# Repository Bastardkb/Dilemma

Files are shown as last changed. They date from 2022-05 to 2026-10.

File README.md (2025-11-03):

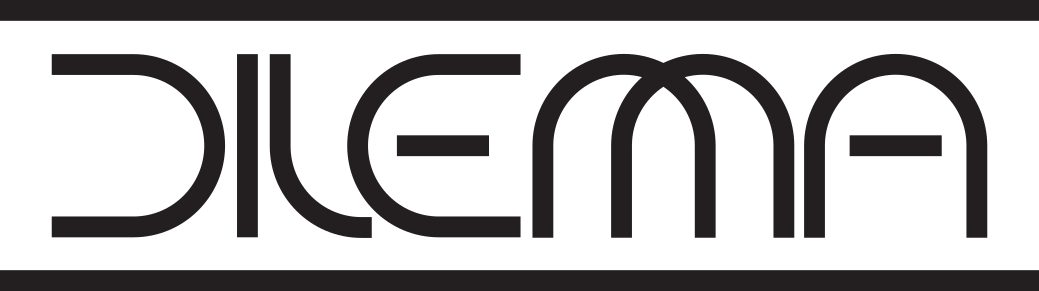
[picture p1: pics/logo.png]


---

The Dilemma is a vertical stagger low-profile keyboard with mods.

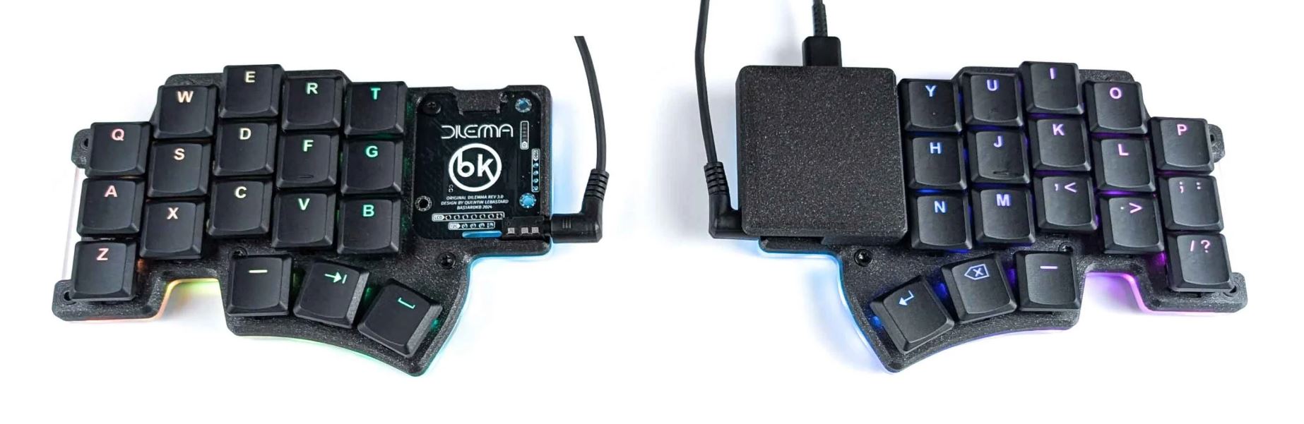
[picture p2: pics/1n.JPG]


## Table of contents

- [Features](#features)
- [Versions](#versions)
- [Required components](#required-components)
  - [3d prints - cases](#3d-prints---cases)
  - [Electronics](#electronics)
  - [Procyon mod](#procyon-mod)
  - [Cirque Trackpad mod](#cirque-trackpad-mod)
  - [Cases](#cases)
    - [Acrylic midplate (v2 only)](#acrylic-midplate-v2-only)
  - [Metal plates](#metal-plates)
  - [Community mods](#community-mods)
  - [Build guide](#build-guide)
  - [Forks](#forks)

---

# Features

- heavy pinky stagger
- MX and choc compatible
- version with hotswap
- underglow RGB, per-key RGB
- 2 Rotary encoders on thumb clusters
- connectors for OLED, LCD

# Versions

There are multiple versions of the dilemma:

| Folder | Name | Size  | PCBA | Trackpad | Switches | Additional features |
| --- | --- | ----- | ---- | --- | --- | --- |
| `3x5_2` | Dilemma DIY V2 | 3x5+2 | no | Cirque | MX, Choc V1 | |
| `3x5_3` | Dilemma V2 | 3x5+3 | yes  | Cirque | MX, Choc V1 | Underglow, per-key RGB, rotary encoders |
| `3x5_3_procyon` | Dilemma V3 hotswap | 3x5+3 | yes  | Procyon  | Choc V1, hotswap | Underglow, per-key RGB, rotary encoders, VIK |
| `4x6_4` | Dilemma MAX | 4x6+4 | yes  | Cirque | MX, Choc V1 | Underglow, per-key RGB, rotary encoders |
| `4x6_4_procyon` | Dilemma MAX V3 hotswap | 4x6+4 | yes  | Procyon  | Choc V1, hotswap | Underglow, per-key RGB, rotary encodersk VIK |

# Required components

## 3d prints - cases

You can find the required 3d prints in the `mechanical` folder.

Most cases require a transparent mid layer to look good. You can either print it, or order it cut in acrylic.

## Electronics

The new revisions are made to be PCBA'd, you can find the gerber, BOM and POS files in the [Releases](https://github.com/bastardkb/dilemma/releases) section.

## Procyon mod

The `dilemma v3 hotswap` is made to work with a [Procyon PCB](https://github.com/bstiq/procyon).

## Cirque Trackpad mod

This mod uses I2C on the DIY version, and SPI on the assembled version.

The DIY version requires removing some resistors from the trackpad:

- R1
- R7 and R8 if you are using a microcontroller that runs on 5V

When installing the trackpad mod, you will need:

| Part name | Amount | Link / source |
| --- | --- | --- |
| M3 screw, torx, 6mm | 4 | Conrad |
| M3x5x5 screw insert | 4 | Aliexpress |
| 3d printed parts | | See `mechanical` folder |
| 40mm cirque trackpad, curved | | |

If building the PCBA version, you will also need:

| Part name | Amount | Link / source |
| --- | --- | --- |
| 12-position FPC cable, 0.5mm pitch, same side contacts, 100mm, type-B | 1 | Farnell |

If building the DIY version, you will also need:

| Part name | Amount | Link / source |
| --- | --- | --- |
| SOD123 Resistor, 5kOhms | 2 | |
| Cables | | |

## Cases

### Acrylic midplate (v2 only)

This case is only compatible with the assembled_v2 version !

Add an underglow effect and a beautiful view into the PCB with those acrylic midplates.

## Metal plates

Optional metal plates enables the use of tripods through magsafe magnets.

Order the [metal plates](mechanical/plates/v2/bottom_metal.dxf) in 3mm thickness. The metal needs to be *magnetized* !
Grab the appropriate DXF from the matched folder.

You will need:

| Part name | Amount | Details |
| --- | --- | --- |
| Metal plates | 2 | 3mm |
| Tripods | 2 | Neewer Z flex |
| Magsafe tripod adapter | 2 | Amazon/Aliexpress |

## Community mods

There are a range of community mods available (hex plates, covers...).

You can find more information in the readme in the `mechanical/community mods` folder.

## Build guide

https://docs.bastardkb.com/bg_dilemma/intro.html

## Forks

- [3x6 version](https://github.com/bstiq/Dilemma_3x6/)
- [3x5 + 3 version](https://github.com/dixls/Dilemma-3mod)

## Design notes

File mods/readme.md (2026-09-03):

# Table of contents
- [Table of contents](#table-of-contents)
- [Cirque holder for flat overlay](#cirque-holder-for-flat-overlay)
  - [BOM](#bom)
  - [Notes](#notes)
- [Blank cover](#blank-cover)
  - [BOM](#bom-1)
  - [Notes](#notes-1)
- [Dilemma Max Tents](#dilemma-max-tents)
- [Dilemma V2  Mounts](#dilemma-v2--mounts)
  - [Table-top tent](#table-top-tent)
    - [Required materials](#required-materials)
  - [Magic arm base](#magic-arm-base)
    - [Required Materials](#required-materials-1)
  - [Design file](#design-file)
- [Trackball mod](#trackball-mod)

# Cirque holder for flat overlay

*This is a community mod, made by Frapiscide*.

A simple holder for the flat overlay cirque trackpad.

Files are in the `40mm_flat_overlay` folder.



## BOM

| Part name | Amount | Notes |
| --- | --- | --- |
| M3x4 Heat-set inserts | 4 |  |
| M3x6 BHCS / SHCS | 4 | |
| 40mm cirque trackpad, flat overlay | 1 | TM040040-2024-302 |
| Pieces of 1.75mm Filament | 3 | 50-75mm is more than enough* |

* If you do not have filament available, alignment key STL's are included

## Notes

- The STL's are pre-oriented for their preferred printing position for FDM
- None of the parts need supports
- The Cirque trackpad holder should work with MX keycaps (18mm x 18mm) but has not been verified. (Rev 1)
- The cirque holder was tested with Cirque Part Number TM040040-2024-302. Others may fit but have not been verified.
- The upper and lower cirque holders require bits of filament and adhesive to hold the two parts together. It was designed this way to prevent the use of supports and maintain dimensional accuracy
- The filament / alignment keys are intentionally a tight fit to maintain alignment.

# Blank cover

*This is a community mod, made by Frapiscide*.

## BOM

| Part name | Amount | Notes |
| --- | --- | --- |
| M3x4 Heat-set inserts | 4 |  |
| M3x6 BHCS / SHCS | 4 | |
| 40mm cirque trackpad, flat overlay | 1 | TM040040-2024-302 |
| Pieces of 1.75mm Filament | 3 | 50-75mm is more than enough* |

## Notes
- The STL's are pre-oriented for their preferred printing position for FDM.
- None of the parts need supports.

# Dilemma Max Tents

*This is a community mod.*

No extras required - same screws and silicon bumpers can be reused.

5,7 and 15 degrees tents are available. Print on flat side. Tolerances might be quite tight, for ABS adjust for shrinkage.

# Dilemma V2  Mounts

*This is a community mod, made by [@brennanxyz](https://github.com/brennanxyz)*.



Files are in the `3x5_3_mounts` folder.

There are two pairs of files for two different tenting solutions, derived from the same base design. One is a table-top set of tent frames, the other is a board bracket meant to be paired with magic arm + clamp tool.

## Table-top tent
These are free-standing, 30° tilting tents that lie on any flat surface. It is designed around the fully-assembled Dilemma V2 stock assembly. 

### Required materials
- (Optional, highly recommended) 8 stick-on rubber feet per half - 7 placed at the tip of each "arm" and once placed at the central nexus point.

## Magic arm base
These are bases that attach to each board half with click-around tabs and are to be paired with a magic-arm mount (such as the SMALLRIG Super Camera Clamp Mount). They are also designed to work with the fully-assembled Dilemma V2 stock assembly.

### Required Materials
- A magic arm + clamp per half. The hole in the base is designed for a 1/4"-20 thread.

## Design file
The design is hosted as an open, free CAD design [on Onshape](https://cad.onshape.com/documents/3a8f56a3f9f7449a7270e859/w/5f722bb2d6442b2bc4cd6168/e/a73e9146248eb1cc832f1ecd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). 
The design by default is for the magic-arm variant, but can be rolled back using the `Rollback bar` to the plane named `DESIGN VARIANT 2` to set the part to the table-top design.

For the magic-arm base, to adjust to a different threaded mount size, edit the sketch named `hole`.

# Trackball mod

*This is a community mod made by Hakuho on Discord*, made for the Dilemma V3.

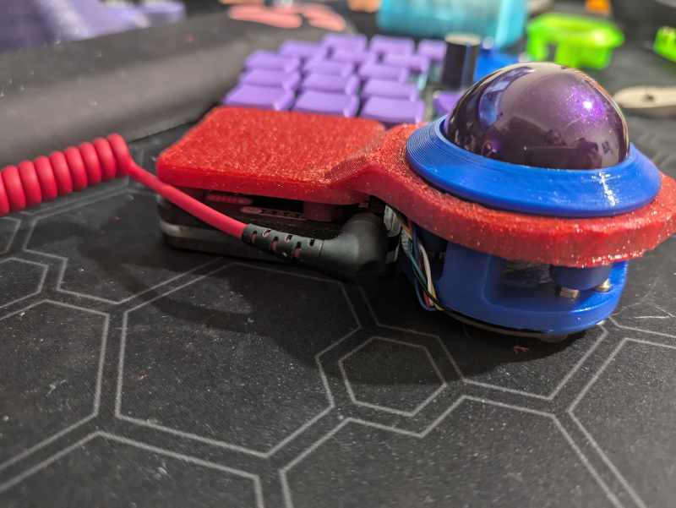
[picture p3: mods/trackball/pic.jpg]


File is in the `mods/trackball` folder.

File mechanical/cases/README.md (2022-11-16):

# 3d printed cases

## Table of contents

- [3d printed thin case](#3d-printed-thin-case)
- [3d printed case with tenting pucks](#3d-printed-case-with-tenting-pucks)
- [3d printed Tenting puck Hex case](#3d-printed-tenting-puck-hex-case)

## 3d printed thin case

Designed for the minimum footprint possible, while still protecting the PCB.

### BOM

| Part name | Amount | Link / source |
| --- | --- | --- |
| M3 screw, torx, 6mm | 6 | Conrad |
| M3 nut | 3 | Conrad |
| Anti slip pads, 10x2mm | 12 | Aliexpress |
| 3d case | 1 right, 1 left | See `mechanical` folder |

### Notes

The case is reversible.

It needs to be printed at 0.2mm layer height supportless specifically for the nut inserts suport-less interfaces. If you are doing a different layer height, use supports. 

## 3d printed case with tenting pucks

Accomodates the Splitkb tenting puck, to be used with a Manfrotto tripod.

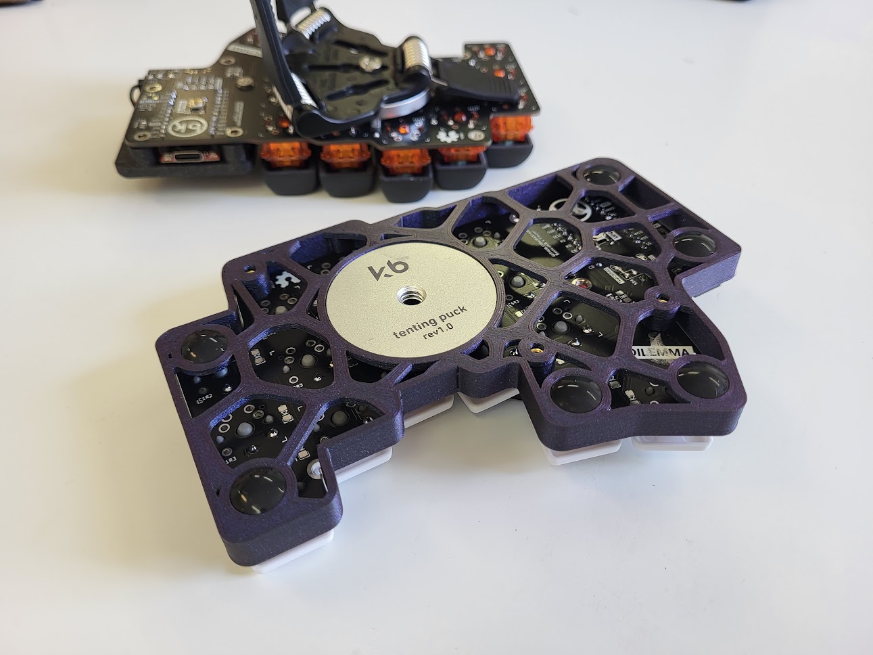
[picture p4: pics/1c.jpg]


### BOM

| Part name | Amount | Link / source |
| --- | --- | --- |
| M3 screw, torx, 6mm | 6 | Conrad |
| M3 nut | 3 | Conrad |
| Anti slip pads, 10x2mm | 12 | Aliexpress |
| Tenting puck assembly  | 1 | Splitkb |
| Manfrotto tripod | 2 | Manfrotto |
| 3d case | 1 right, 1 left | See `mechanical` folder |

### Notes

The case is reversible.

It needs to be printed at 0.2mm layer height supportless specifically for the nut inserts suport-less interfaces. If you are doing a different layer height, use supports.

## 3d printed Tenting puck Hex case

Credit: Frapiscide.

Old-school hex-style cases for the Manfrotto tripod.

There are 2 versions available:

- with a hole for the SplitKB tenting puck
- with an integrated 3d printed puck assembly, to screw the tripod in directly. 

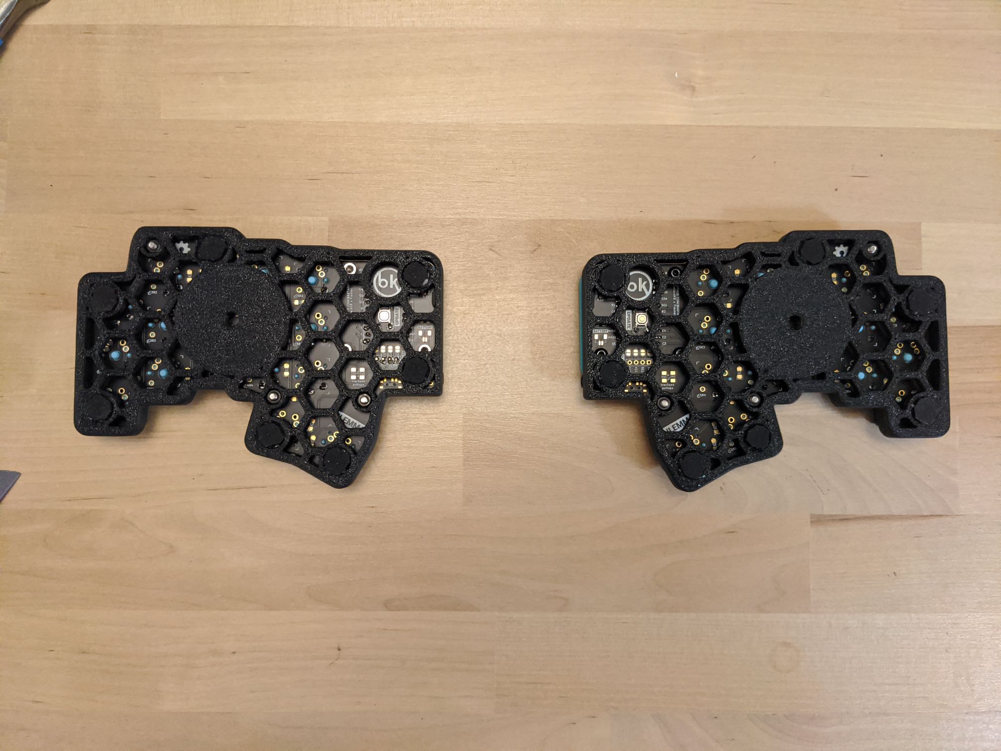
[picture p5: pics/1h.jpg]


### BOM

| Part name | Amount | Notes |
| --- | --- | --- |
| M3x6 BHCS | 3 | M3x8 BHCS work too |
| M3 Hex Nut | 3 | |
| 3d printed case | 2 | Right / Left* |

* You will need to print 2 cases - you can reverse it in your slicing software.

There are 2 versions:
- integrated holes to screw the manfrotto tripod directly
- hole for the splitkb tenting puck 

### Notes

- The case was designed around the DIY v0.1c PCB. Other versions may work but have not been verified
- The STL's are pre-oriented for their preferred printing position for FDM
- None of the parts need supports
- The case has .25mm of clearance all around the perimeter of the PCB
- The parts can be mirrored for whichever side you want the part for. The case and blank cover are originally modelled for the left side and the cirque holder for the right side. (Rev 1)

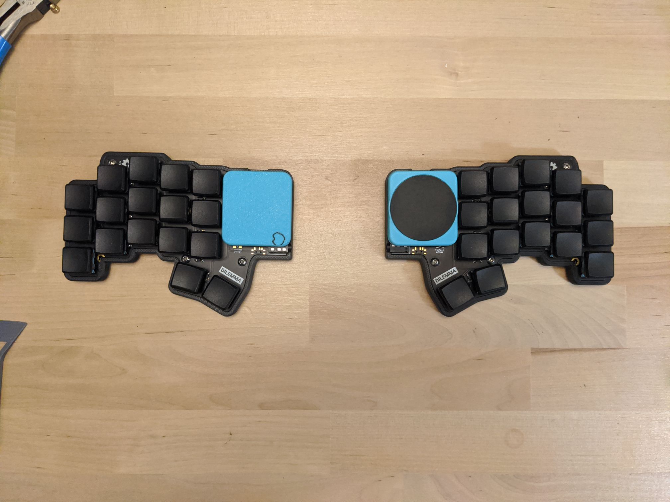
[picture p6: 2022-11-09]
pics/1i.jpg

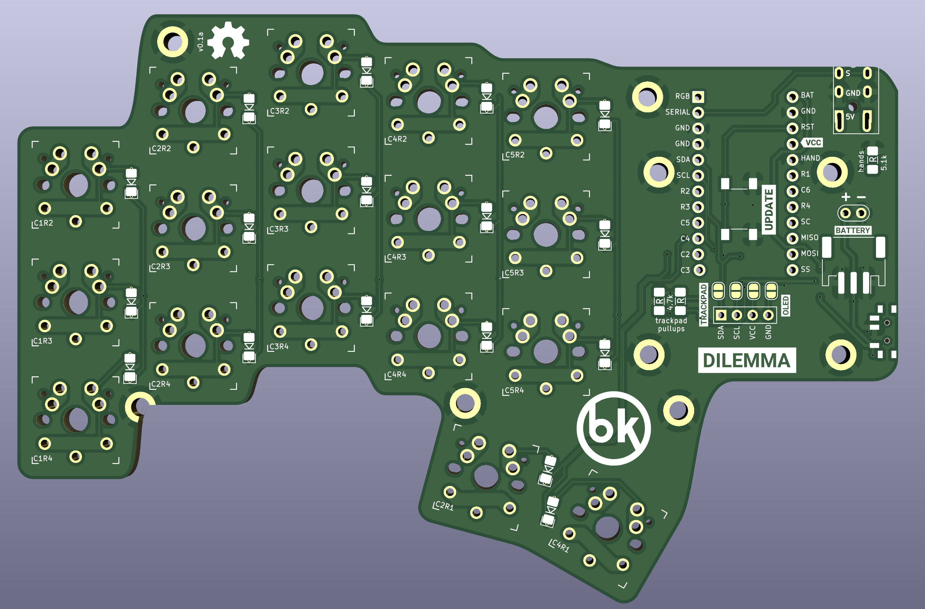
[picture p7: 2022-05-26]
pics/1a.PNG

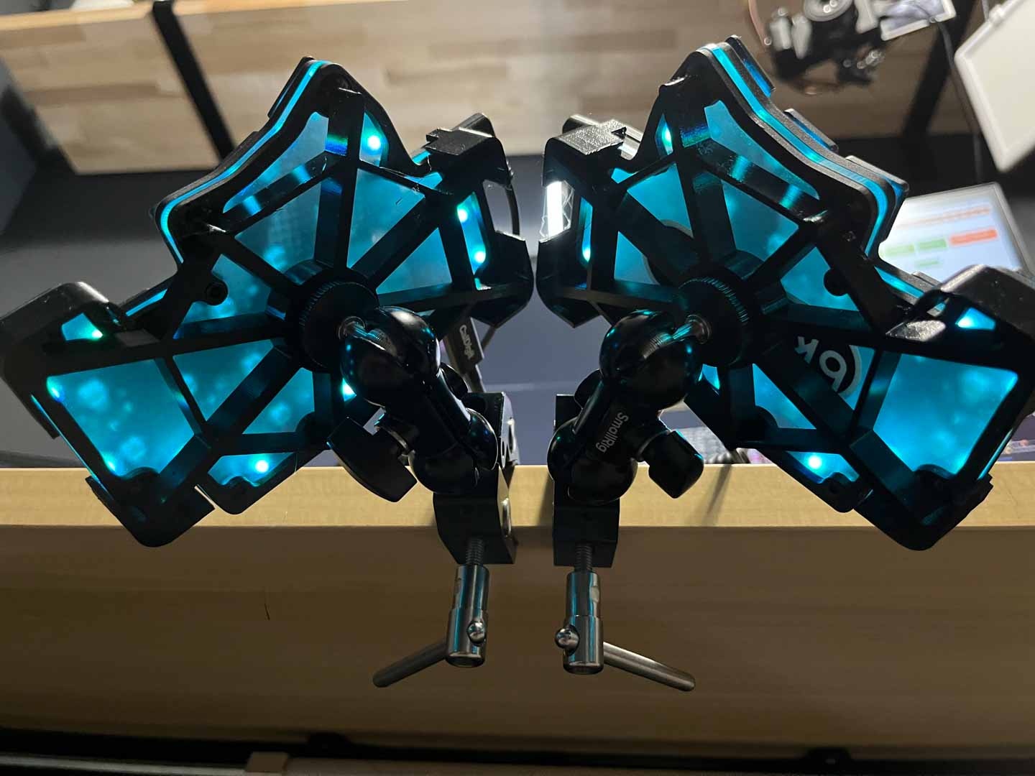
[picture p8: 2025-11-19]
pics/1o.jpg

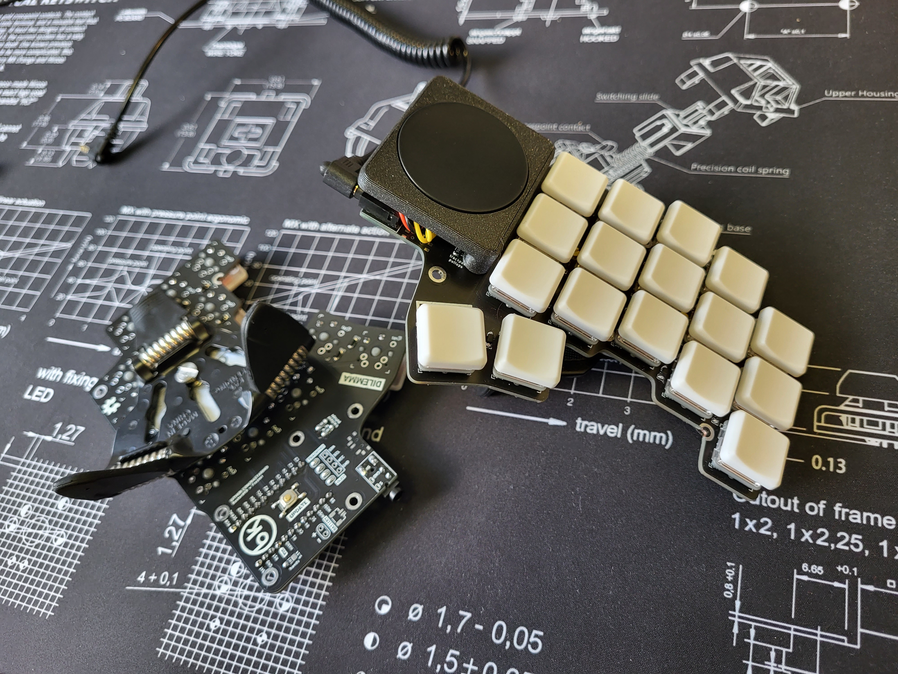
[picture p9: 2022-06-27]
pics/1b.jpg

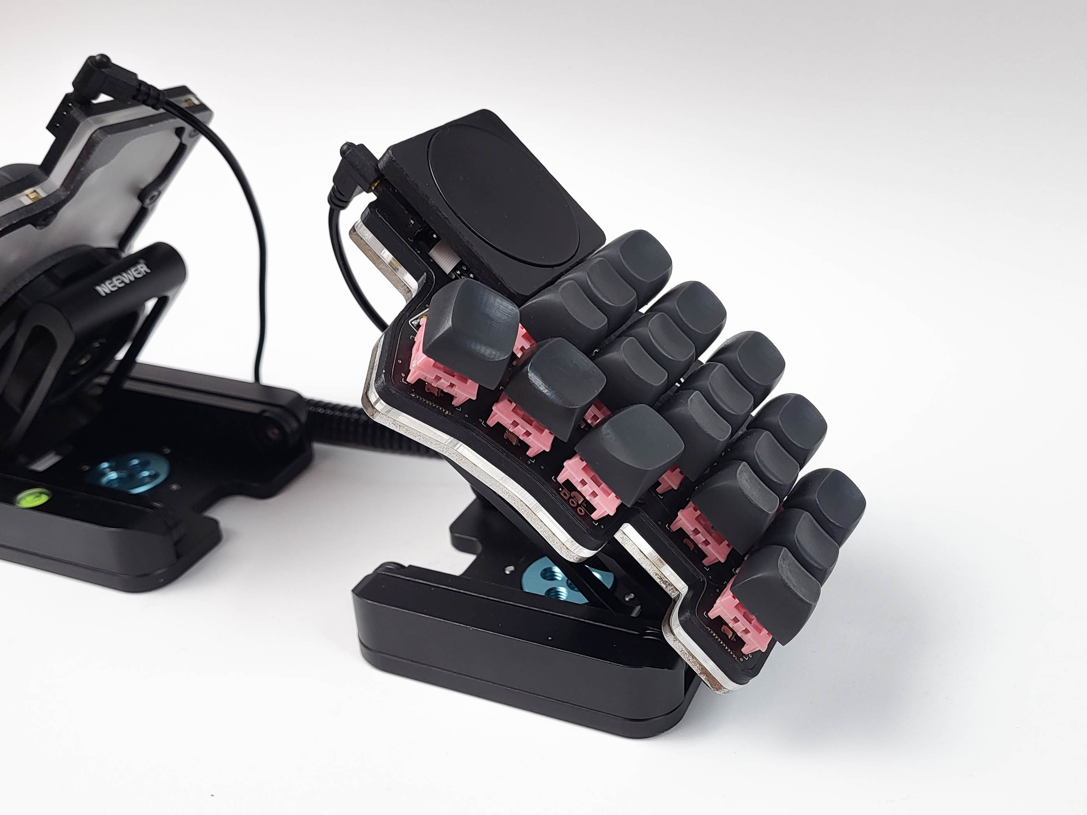
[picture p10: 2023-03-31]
pics/1m.jpg

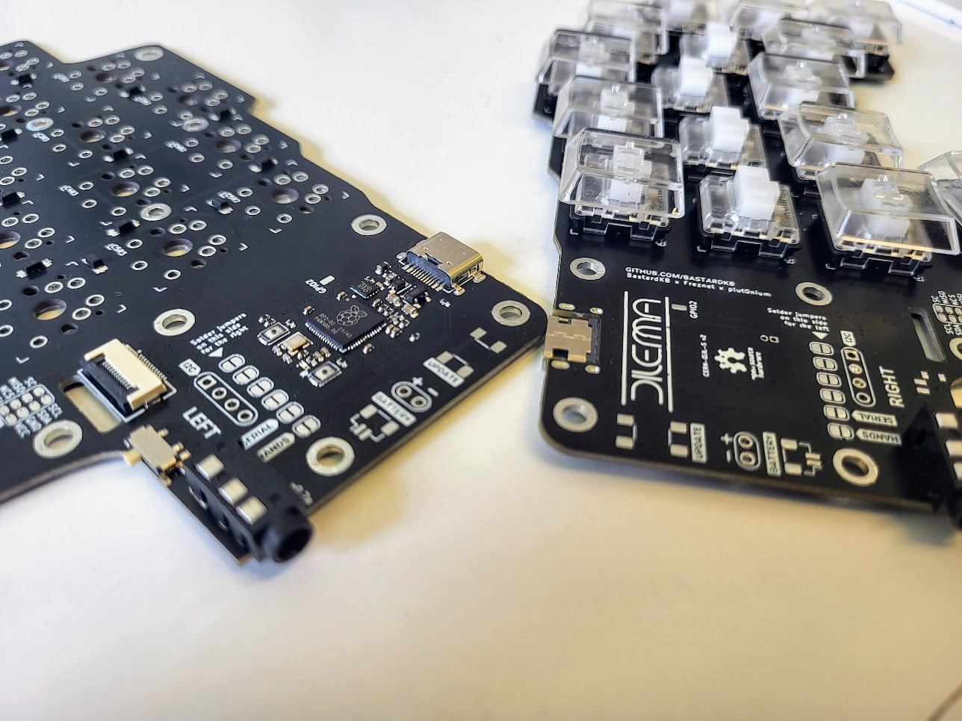
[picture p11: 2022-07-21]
pics/1d.png

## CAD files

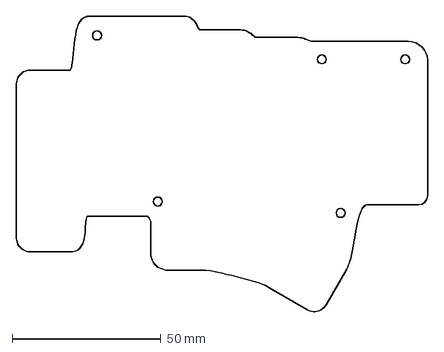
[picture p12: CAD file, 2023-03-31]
mechanical/cases/3x5_3/bottom_acry_full.dxf
138.0 x 99.2 mm

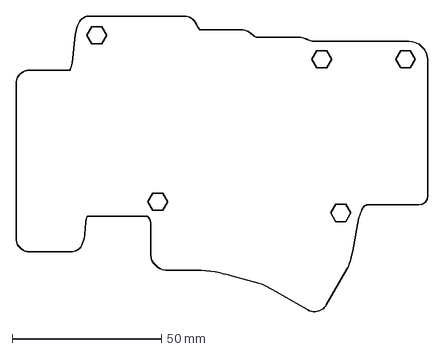
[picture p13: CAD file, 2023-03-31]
mechanical/cases/3x5_3/mid_acry_full.dxf
138.0 x 99.2 mm

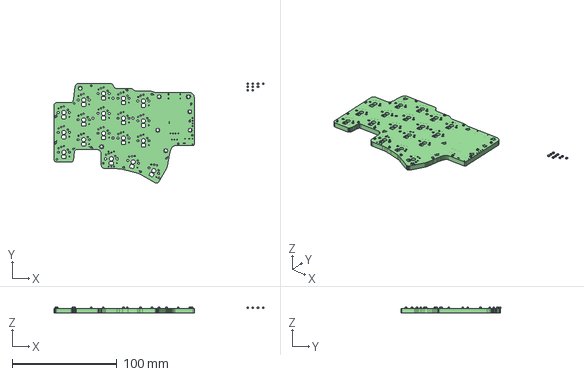
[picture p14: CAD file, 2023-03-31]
3x5_3_procyon/dilemma.step
200.7 x 96.0 x 5.28 mm
dilemma PCB

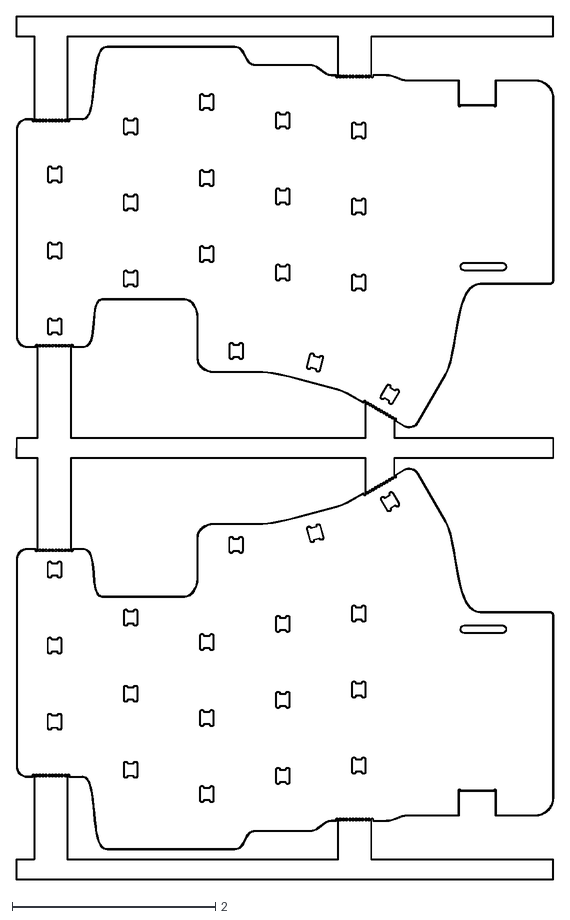
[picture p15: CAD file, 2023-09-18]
3x5_3_procyon/gerber/dilemma-Edge_Cuts.dxf
5.29 x 8.49

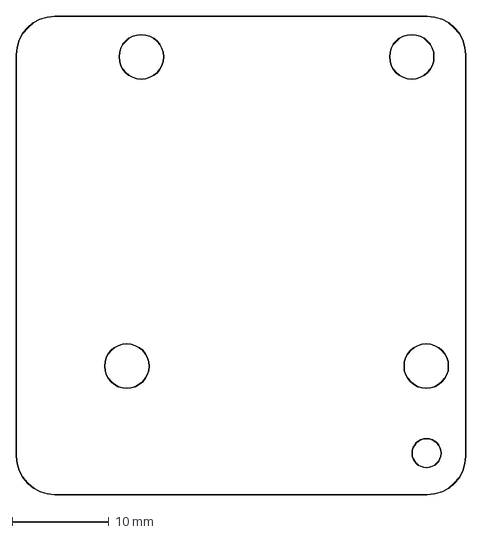
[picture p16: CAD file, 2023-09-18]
4x6_4/trackpad.dxf
46.5 x 49.5 mm

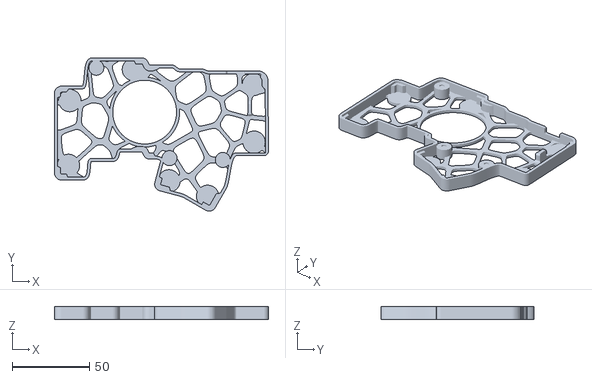
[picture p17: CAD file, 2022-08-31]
mechanical/cases/3x5_2/tenting_puck/tenting_puck_v3_26.stl
138.3 x 99.1 x 8.40

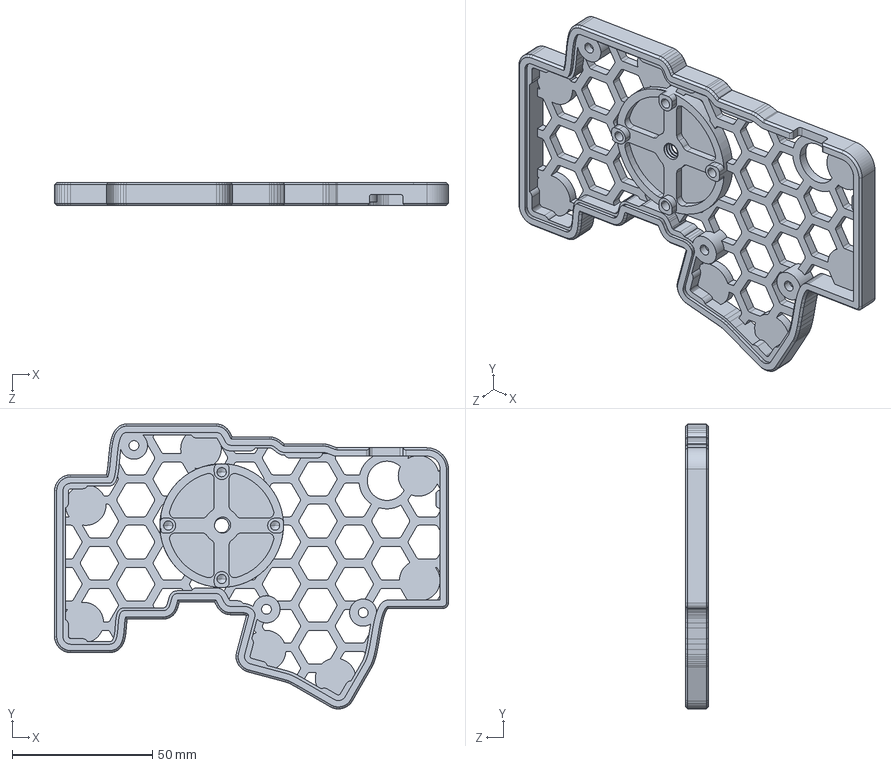
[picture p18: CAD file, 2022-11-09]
mechanical/cases/3x5_2/tenting_puck_hex/STEP/Dilemma Case Integrated Tenting Puck.STEP
140.5 x 101.6 x 8.20 mm

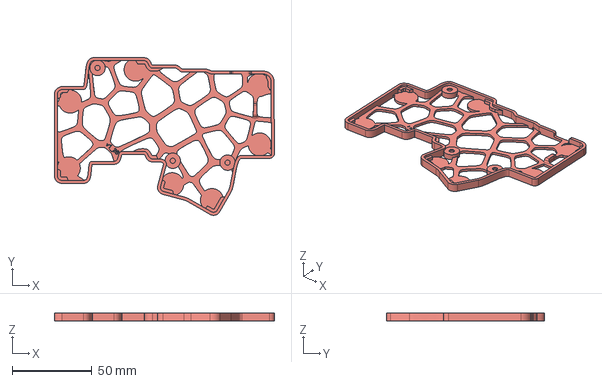
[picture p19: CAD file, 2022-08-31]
mechanical/cases/3x5_2/thin/dilemma_nuts v27.step
138.3 x 99.1 x 4.90 mm

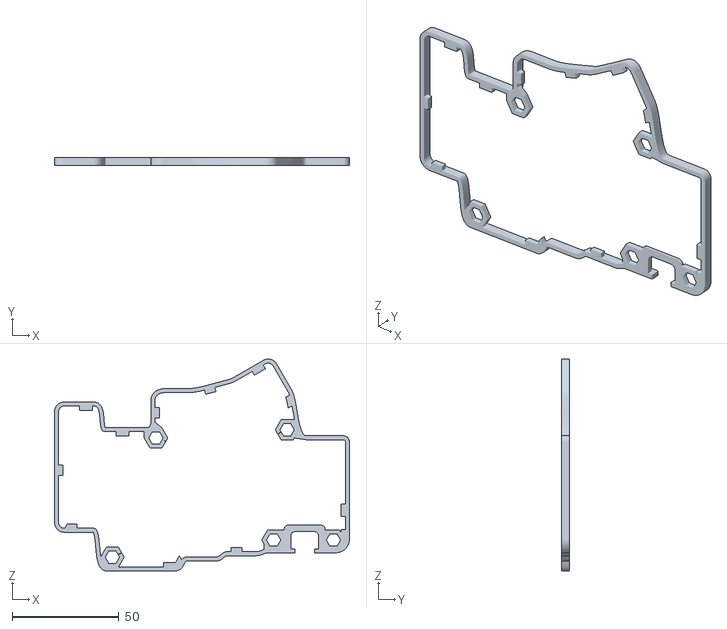
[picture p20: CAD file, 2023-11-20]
mechanical/cases/3x5_3/top.stl
138.0 x 3.80 x 99.1

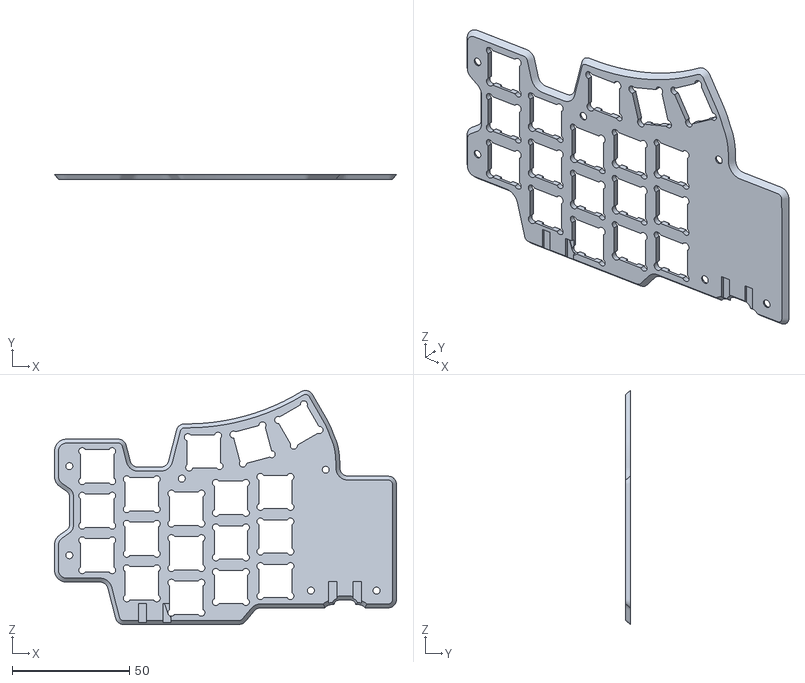
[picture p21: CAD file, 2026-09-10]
mechanical/cases/3x5_3_trackball/top left.stl
145.8 x 2.00 x 99.8

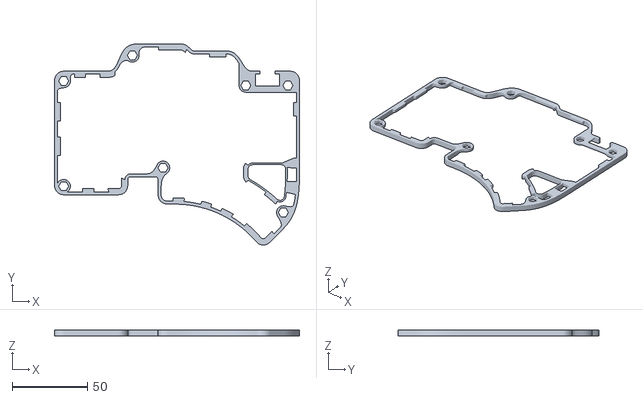
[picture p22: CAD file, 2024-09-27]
mechanical/cases/4x6_4/top.stl
162.9 x 133.7 x 3.80

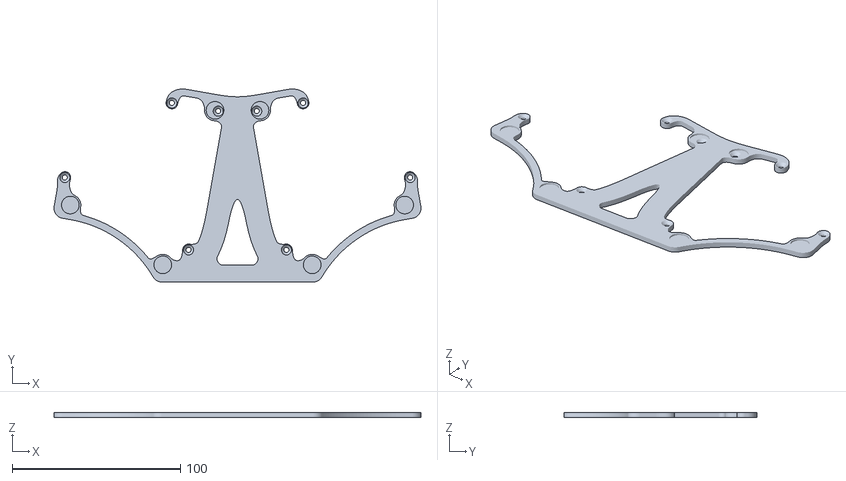
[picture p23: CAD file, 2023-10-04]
mechanical/cases/4x6_4/unibody/center_20deg.stl
218.4 x 114.9 x 3.00

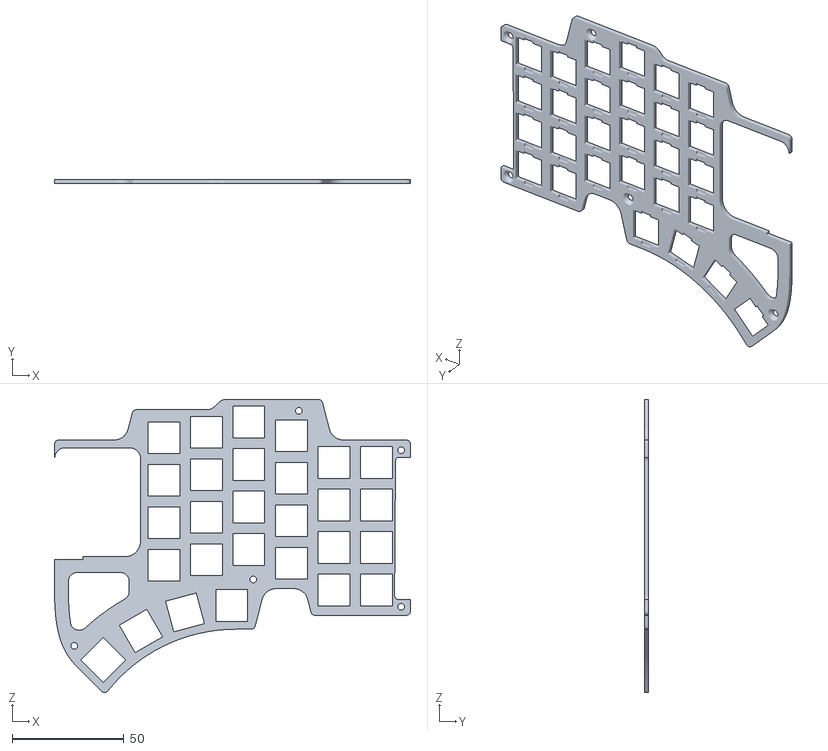
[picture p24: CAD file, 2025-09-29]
mechanical/cases/4x6_4_hotswap/plate_left.stl
159.1 x 2.00 x 131.0

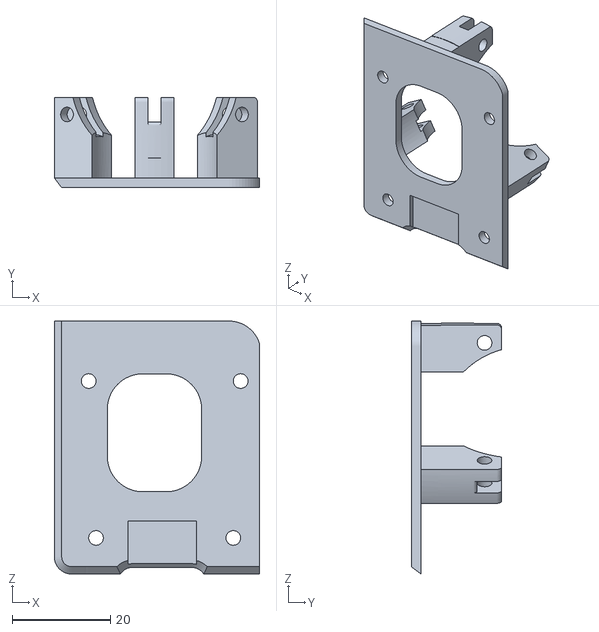
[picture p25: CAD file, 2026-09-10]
mechanical/trackball/bearing holder.stl
41.9 x 18.5 x 51.6

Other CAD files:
mechanical/trackpad/35mm/bottom2.stl
mechanical/trackpad/40mm/top.stl
mechanical/trackpad/procyon/hider_4x6.stl
3x5_2/dilemma.step
4x6_4/dilemma-Edge_Cuts.dxf
mechanical/cases/3x5_2/tenting_puck_hex/Dilemma Case Integrated Tenting Puck.STL
mechanical/cases/3x5_2/tenting_puck_hex/Dilemma Case Tenting Puck Opening.STL
mechanical/cases/3x5_2/tenting_puck_hex/STEP/Dilemma Case Tenting Puck Opening.STEP
mechanical/cases/3x5_2/thin/thin_v1_26.stl
mechanical/cases/3x5_3/bottom.stl
mechanical/cases/3x5_3/bottom_metal.dxf
mechanical/cases/3x5_3_hotswap/bottom.stl
mechanical/cases/3x5_3_hotswap/mid.stl
mechanical/cases/3x5_3_hotswap/midplate.dxf
mechanical/cases/3x5_3_hotswap/plate_left.stl
mechanical/cases/3x5_3_hotswap/plate_right.stl
mechanical/cases/3x5_3_trackball/bottom.stl
mechanical/cases/3x5_3_trackball/contour.stl
mechanical/cases/3x5_3_trackball/spacer.stl
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

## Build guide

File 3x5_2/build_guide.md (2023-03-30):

# Dilemma DIY build guide

This guide was done for a modified version of DIY Dilemma, however steps should be the same as the modification changes only the amount of switches.

The Dilemma PCB is a reversible PCB meaning that both halves are the same but because the bottom part is mirrored part of the top part it is possible to use it for the other side.

The current PCB project is done in a way that if you put two halves in front of you then the "front" ("red") layer is on the left side and the "bottom" ("blue") layer is on the right.

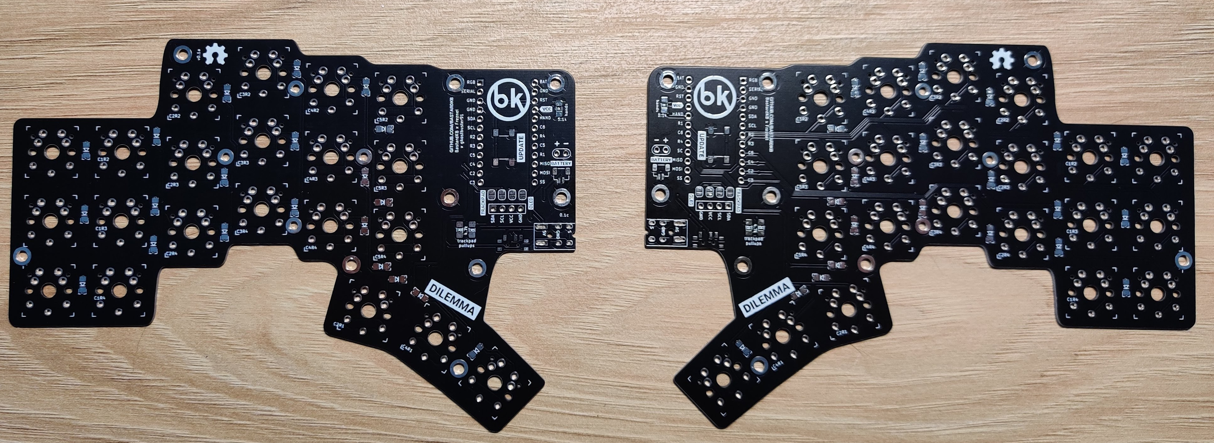
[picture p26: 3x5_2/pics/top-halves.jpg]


1. Soldering jumpers (optional)

This step is optional, do it only if you want to use OLED or I2C deviced on a particular side.

Jumpers have to be soldered on the "front" sides of both halves. That means that on the left side you will have to solder them on the top, and on the right side - on the bottom.

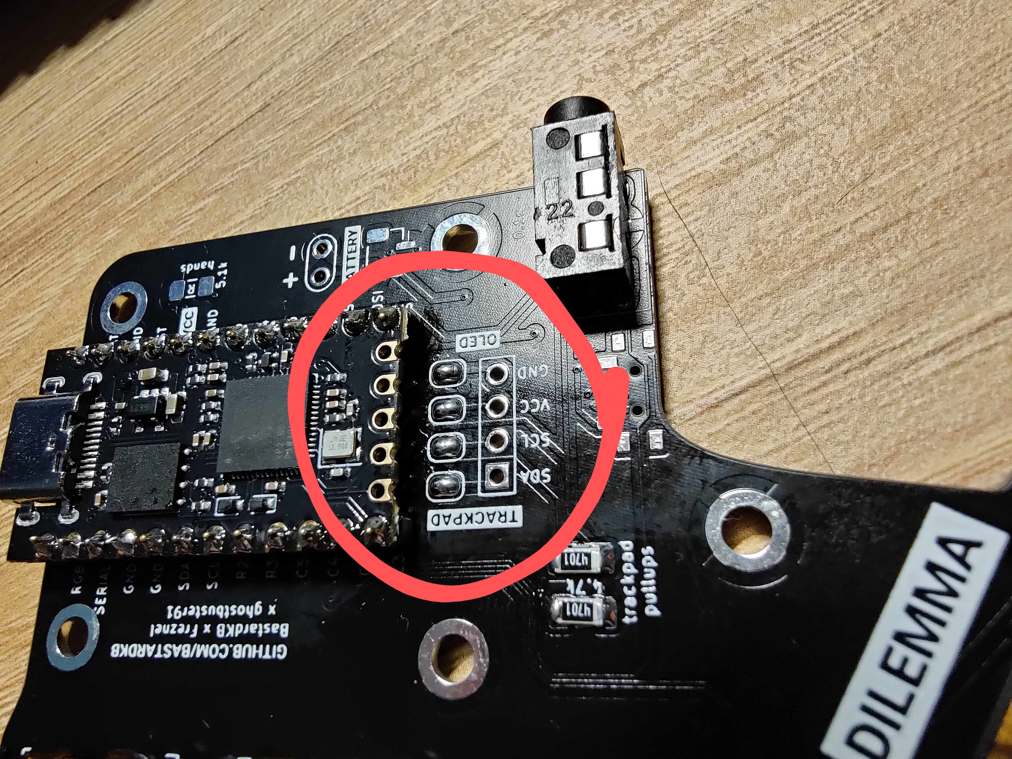
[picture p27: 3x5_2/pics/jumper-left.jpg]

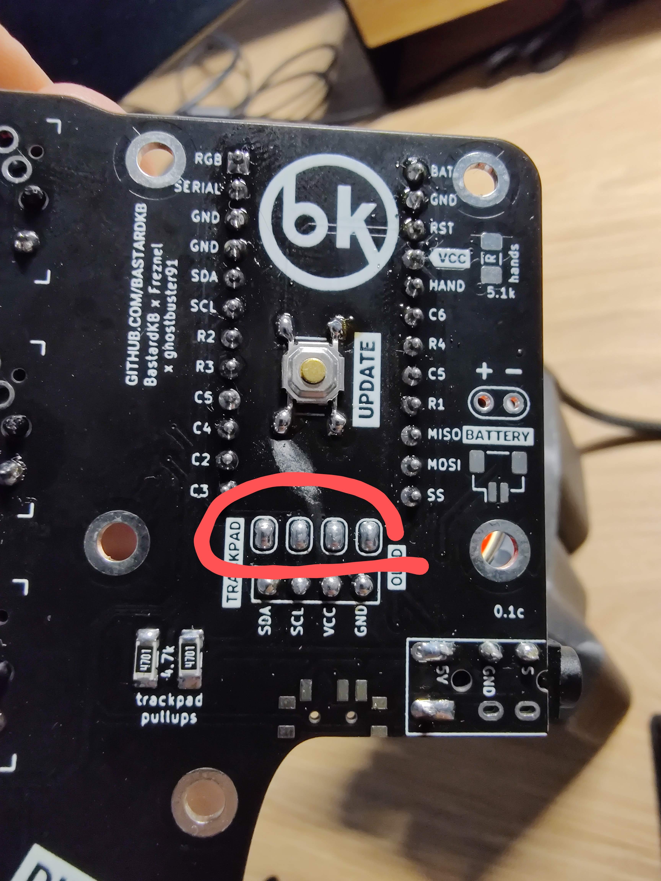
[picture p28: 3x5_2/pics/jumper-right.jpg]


2. Install controller

_The Dilemma is only compatible with rp2040 boards._

To check if your controller is compatible refer to the following table: https://github.com/Bastardkb/technical-docs/wiki/RP2040-controllers

_Important_ Since one of the halves is flipped you will also have to flip one of yours controllers. Follow the legends both on the controller and the PCB to figuer out how to install it.
In my case the controller on the left had components facing up, and the one on the right side had components facing down.

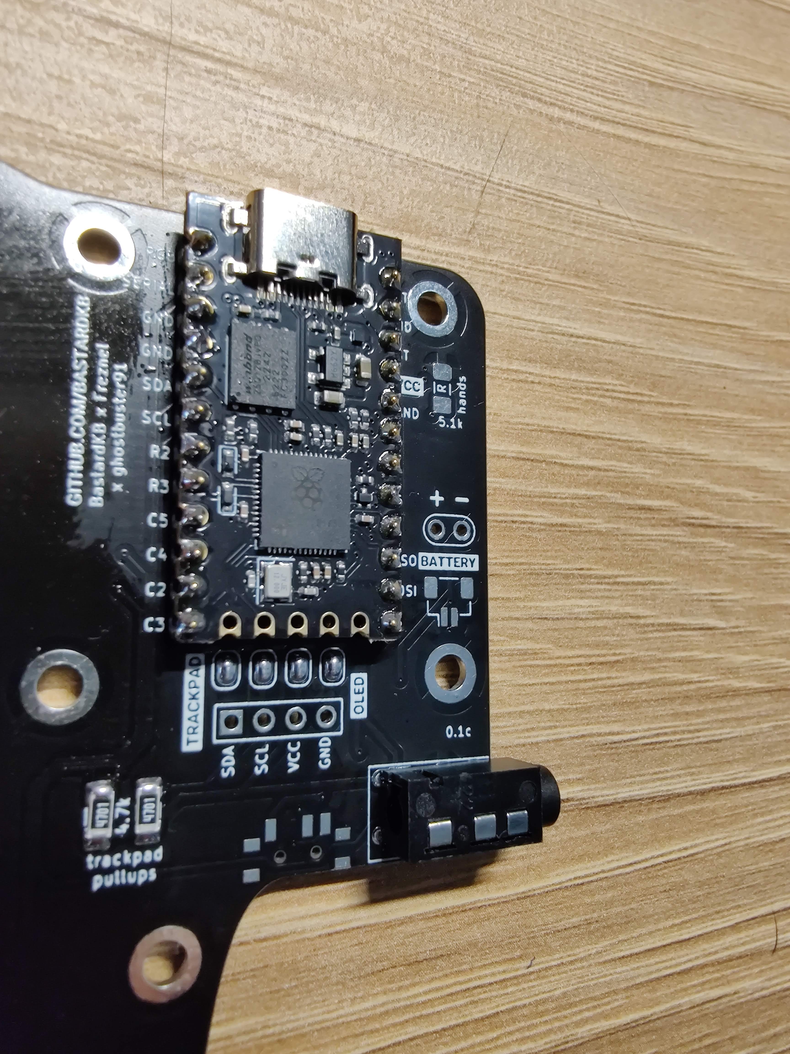
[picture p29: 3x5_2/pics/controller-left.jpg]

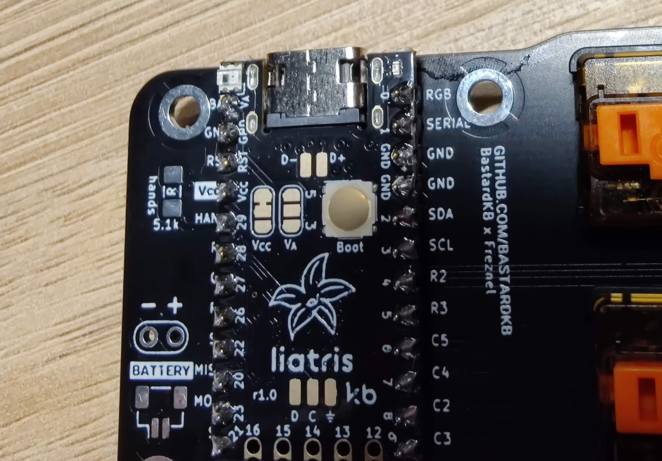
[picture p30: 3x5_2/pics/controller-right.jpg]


3. Install the audio jack

Nothing special here. As an additional note it can be soldered on the top as well as on the bottom.

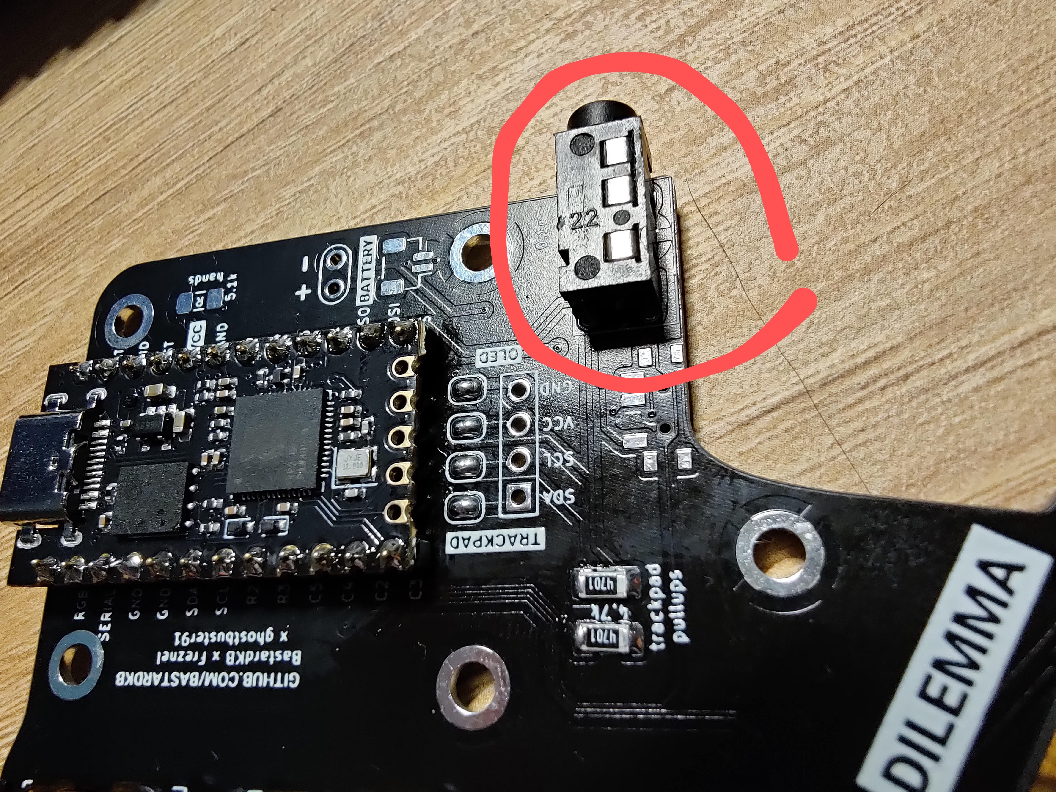
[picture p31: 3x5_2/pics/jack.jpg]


4. Install diodes

Again, nothing fancy. Can be soldered on either side. Pay attention to the orientation.

5. Install switches

Solder in your switches of preference.

6. Install reset button

Solder in reset buttons on the bottom of each half.

7. Enable handness (optional)

There is an optional feature called handness that allows keyboard to detect which side is master regardless of which one is connected to the PC.

https://github.com/Bastardkb/bastardkb-qmk/blob/dc3e11edcca343fe1a2ba550949bebeea407f8b9/keyboards/bastardkb/dilemma/3x5_2/splinky/config.h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

```c
// To use the handedness pin, resistors need to be installed on the PCB.
// If so, uncomment the following code, and undefine MASTER_RIGHT above.
//#define SPLIT_HAND_PIN GP29
// If you've soldered the handedness pull-up on the upper side instead of the
// left one, uncomment the following line.
//#define SPLIT_HAND_PIN_LOW_IS_LEFT // High -> right, Low -> left.
```

The idea is simple - one side pulls the pin high, and the other pulls the pin low.

For this to work "hand" resistors have to be installed on both sides on the same "side". Meaning that either both go on the top or one the bottom of the PCB.

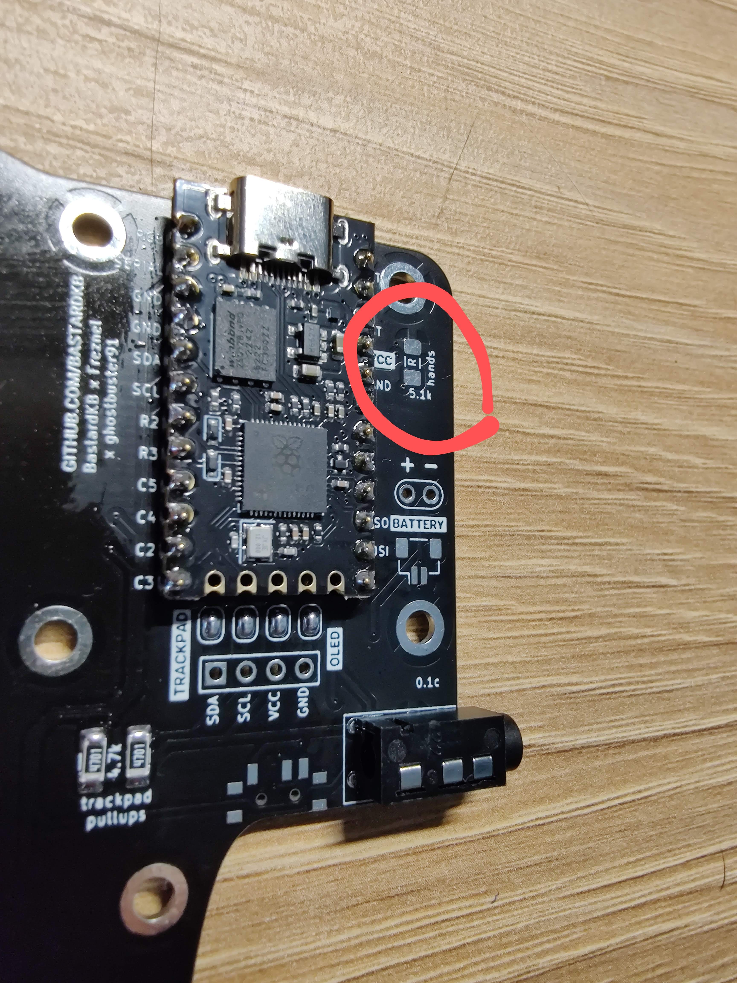
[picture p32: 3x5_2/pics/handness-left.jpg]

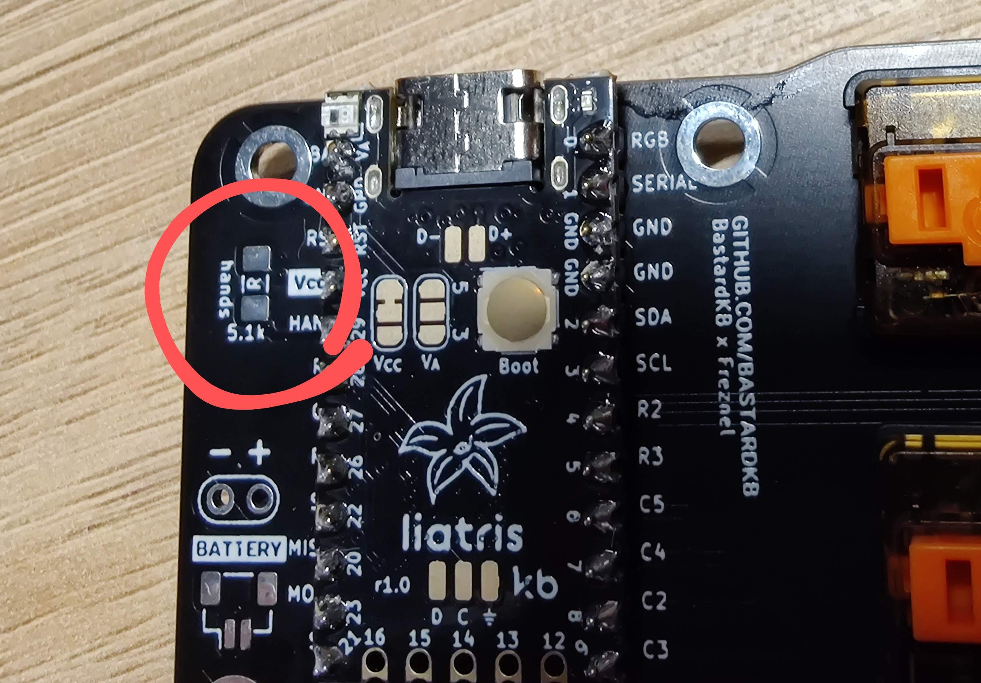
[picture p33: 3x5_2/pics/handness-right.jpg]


8. Install cirque trackpad (optional)

The are three resistors that are important for us: R1, R7 and R8. R1 controls whether the device works in I2C or SPI mode. For the DIY Dilemma we need it to work in I2C mode which means that we need to desolder R1.
R7 and R8 need to be desoldered if you are going to supply the device with 5V. If you are going to power it with 3V then its fine and you don't have to touch them. For more info refer to https://github.com/Keycapsss/cirque-trackpad

Cirque trackpad is connected with the board using 4 pins: GND, VCC, SCL(clock) and SDA(data). That means to you need to figure out what kind of voltage you have on VCC.
You can check it in the specification of your controller, or you can measure it.

After that you need to connect pads from the PCB with corresponding pads on the Cirque trackpad.

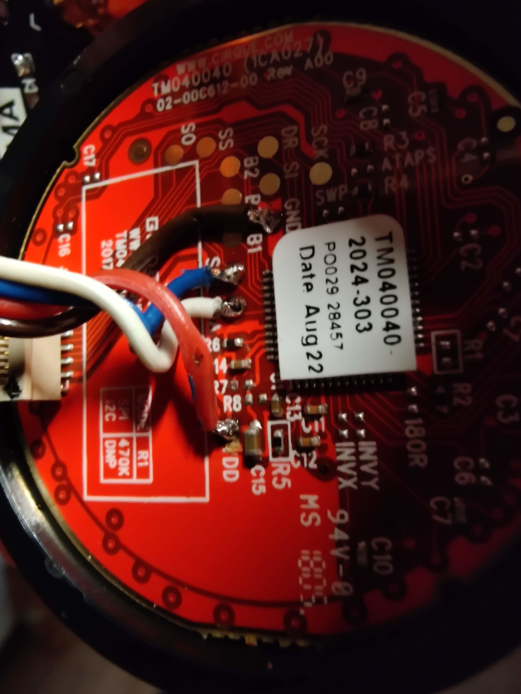
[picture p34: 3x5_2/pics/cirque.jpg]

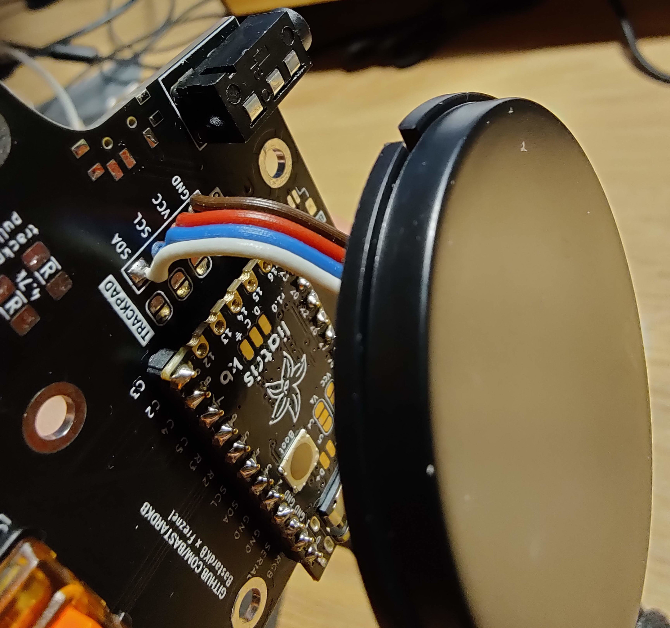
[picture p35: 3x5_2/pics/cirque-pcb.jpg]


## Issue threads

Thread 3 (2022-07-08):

Dilemma integrated review

KarlK90, 2022-07-08:
@bstiq Pretty much the same feedback as on the splintegrated - minus the ideal diode stuff as the dilemma doesn't feature RGB

# Recommendations

1. ESD protection for USB-C port and split-comms port on data lines only or including cc lines (like shown)
	- protects against static discharge (charged cloths!) and subsequent destruction of any IC
	- recommendation StMicroelectronics (or knock-off manufacturer) **USBLC6-2** in either SOT23-6L *C7519* or the smaller SOT-666 *C15999* package or the **USBLC6-4** as shown

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

2. Support full-duplex serial on the TRRS jack
	- much higher baudrates are possible, which in turn shortens the time to send data across the halfs. Thus frees up processing power
	- the kids want it :P

3. Expose SWD debugging headers, great for devs like me :-). The following signals need to broken out, preferably as a 2.54mm pinheader (3 or 4 pin)
	- SWCLK
	- SWD
	- GND
	- 3.3V (optional, but usefull if available)

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

4. (optional) Supply +5V to the other split half instead of +3.3V

bstiq, 2022-07-11:
More things to do :

- [ ] remove on/off button
- [ ] fix gpio2 text (not oriented correctly)
- [ ] add more gpio headers

bstiq, 2022-08-09:
Issue 3 is done.
Issue 2: At the moment I won't support it.
Issue 1: I am creating a separate issue for it

Closed 2022-08-09.

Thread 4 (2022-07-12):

Small tweaks

bstiq, 2022-07-12:
More things to do :

- [x] remove on/off button
- [x] fix gpio2 text (not oriented correctly)
- [ ] ~~add more gpio headers~~
- [x] add ohl v2 s text in design files
- [ ] ~~make spi hole look better~~
- [x] rename files from `0xb2` to `dilemma`

Others:

- [ ] build guides
- [ ] mod guides - tenting puck
- [ ] upload case files
- [ ] 2 folders : `handsoldered`, and `assembled`
- [x] add CE marking
- [x] order ROHS

Closed 2022-07-21.

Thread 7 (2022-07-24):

Dilemma DIY - on off button not wired properly

bstiq, 2022-07-24:
As mentioned by charly and freznel
When battery is conected, Vcc and Gnd are connected

Fix: on/off button should be wired like on the adapter v2

bstiq, 2022-07-24:
Tag DIY0.1c should fix it.

@freznel10 could you maybe take a look at the schematic and wiring when you have time to confirm? Then I will order new DIY ones with the next PCB order.

0xcharly, 2022-07-24:
I'm no expert, but from a cursory look, this fix LGTM.  I'll order a small batch to test.

bstiq, 2022-08-09:
@0xcharly Can you confirm everything works ?

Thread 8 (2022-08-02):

Beta test feedback

keyboard-magpie, 2022-08-02:
Not an issue but thought this would be appropriate place to add feedback, in no particular order:

1. Build guide- suggest add steps for case mounting- was a new technique for me
2. FFC cable steps- I couldn't get it to sit quite neatly with your steps- needed one more fold

More to follow as I finish the build, if i didn't document these fresh I'd for get them!

keyboard-magpie, 2022-08-02:
3. I'm aware it's specified on the github page, but it's probably worth adding specifics about the cirque resistors to the build guide (i.e. for the dilemma assembled DO NOT alter any of the resistors).

KarlK90, 2022-08-05:
1. Mouse bites needed sanding to fit properly in the cases, this could either be a post-process step at bastardkb or be done by the user. Later should probably be documented.
2. Cases tend to tip over on the upper end when used with MX switches and high profile keycaps. Another bumper around the location shown in the picture would be great:
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
3. Another "high profile" track-pad assembly for usage with MX switches and high profile keycaps would be awesome. In this combination the trackpad sits quite recessed.

ykz89, 2022-08-05:
1. Not sure if this is already addressed, but with the low profile case, there is no room for the protruding button of the power switch on the right half. I have the assembled version, so I desoldered the power switches anyway.
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

2. The reset button is kinda hard to reach, and I feel like it needs a screw here; when pressing the reset button, you're pushing the pcb out of the case.
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

0xcharly, 2022-08-07:
Built: Dilemma Assembled Beta tester edition
Switches: Choc v1
Case: low profile

The overall build experience is great. I went out of my way to sand the mouse bites and clean the flux, but otherwise a very fast board to assemble, on par with more classic keyboards assembly.

## Points that have been mentioned already

1. Add a list of tools required at the top of the build guide. That will allow people to get ready ahead of time and not get stuck during assembly: in addition to Torx T-10H, one need some way to sand out the mouse bites (with either a file or sandpaper).

1. The case is in the way of the reset button. It is still accessible, but partially obstructed by the case.

1. The battery features are confusing. The board is not made for wireless, so the on/off switch (which needs to be de-assembled), and the 2 battery connector footprints are surprising. Removing those footprints would give enough space to move the reset button further down (see previous point).

1. The extra half screw hole on the bottom left looks like an oversight and a production issue, in particular because it is not used for assembly. I would either remove it, or make it whole and use it for assembly.

## Other notes

1. While the PCB does not pop out of the case, it feels like a couple screws are missing to properly secure it. At least in the bottom left and top right (for the left side, and top left/bottom right on the right side).

1. The low profile case is missing half a cm of tolerance for the USB-C port cutout: on the right side, it looks like the USB-C port is pushing against the cut out, so the PCB is not sitting perfectly flush (although, it's pretty close) and can pop out of the case in that corner more easily than on the left side

1. The ribbon cable assembly is **MUCH** better than with i2c, but I don't feel very comfortable having to twist the ribbon (which makes assembly and re-assembly a bit dangerous). Flipping either the trackpad or the ribbon connector on the PCB should allow for keeping the ribbon flat/not-twisted.

1. The left side feels "empty", like it's missing something. In particular with all the footprints available on the board, it feels incomplete. On the other hand, seeing the controller exposed is pretty cool IMO. Maybe some sort of 3D printed holder and/or see-through acrylic piece would complete it nicely, and provide a better visual and structural balance with the trackpad side.

1. One advantage of this keyboard over more complicated dacman builds is that you can test the PCB early. I'd recommend including a "Test the PCB" step in the guide by using either Via or Vial (the downside of Vial is that you need to "unlock" the PCB, which requires both halves and serial working, and 2 pairs of tweezers, but the downside of Via is that you need to side-load the JSON, unless we go through the process of upstreaming that part – I heard Via opened up more of it's source code and made contributing new JSON easier). For both tool, we can now point to the web-hosted version from the build guide.

bstiq, 2022-08-08:
Thank you so much everyone !

I created issues based on your feedback.

@ykz89 you will notice there's nothing about the reset button, that's because it's fixed.

@0xcharly , the power stuff is also removed

bstiq, 2022-09-16:
@0xcharly happy to let you know that the 1.2 RC fixes the cable issue ! I will do a few full build with them to test everything out then deploy on the next batch.
Thanks for the feedback !

0xcharly, 2022-09-16:
Awesome, thanks for addressing this! Can't wait to try it out.

Closed 2022-08-08.

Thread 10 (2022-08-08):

Build guide/docs enhancements

bstiq, 2022-08-08:
Build guide:

- [ ] New section : case installation
- [x] FFC cable installation: needs one more fold ?
- [x] Add specifics about the resistors of the trackpad - NO need to remove them
- [x] Add a list of tools required: torx/flat screwdriver, sandpaper for mouse bites ?
- [x] Add a "test the PCB" step, after installing trackpad (before switches), with tweezers. Mention they come pre flashed

Github:

- [x] add Dilemma logo - ok, bd35f46684b87e2fe0ec71b520025e19447a7e75
- [ ] add open source logo
- [x] add buttons with status, issues, etc - ok, bd35f46684b87e2fe0ec71b520025e19447a7e75

Others:

- [ ] Create pdf with features to include in it
- [ ] main website page - add dilemma logo
- [x] Mailchimp email for official announcement

bstiq, 2022-08-09:
In the required tools part, I didn't include sandpaper, as the next rev of the assembled PCB should fix this issue.

Closed 2023-02-27.

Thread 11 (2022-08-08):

3d case improvements

bstiq, 2022-08-08:
Quoting KarlK90:

- [x] Cases tend to tip over on the upper end when used with MX switches and high profile keycaps. Another bumper around the location shown in the picture would be great(pic removed)

- [ ] A raised trackpad assembly for MX and high pro keycaps would be nice
- [x] (as per charly) The low profile case is missing half a cm of tolerance for the USB-C port cutout: on the right side, it looks like the USB-C port is pushing against the cut out, so the PCB is not sitting perfectly flush (although, it's pretty close) and can pop out of the case in that corner more easily than on the left side

- [x] test new models (low pro and puck) - 36aa2f083001e817e47ebb432f494e14338da048

bstiq, 2022-08-09:
New case models are online and confirmed working !

bstiq, 2022-08-31:
Closing this, will not do the raised trackpad at this moment.

Closed 2022-08-31.

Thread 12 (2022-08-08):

PCB improvements

bstiq, 2022-08-08:
- [x] Make panel, as the current PCB needs sanding on mouse bites
- [x] Check I2C pads: they seem to be flipped top/bottom? - fixed by eed4a4ee3b34df7b67623bcbd8bac768d1bb776e
- [x] Remove half screw
- [x] round angle around audio jack - ok, 494d98090b708812a662c635ddf28926d45a2854

## Ribbon cable
having to flip it is not nice.

- [ ] fix it

Ideas:
- rotate trackpad 180, use longer cable, design 3d adapter
- flip fpc 180

bstiq, 2022-08-08:
It seems the FPC cables are only available in 5cm or 15cm/20cm, so rotating the trackpad will prove complicated

bstiq, 2022-08-08:
Re: I2C pads, I confirm they are reversed

bstiq, 2022-08-09:
For standard PCBA, JLC needs rails and fiducials.

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

bstiq, 2022-08-09:
At the moment, I will leave the ribbon assembly as is, as here is no easy fix.

Closed 2022-08-09.

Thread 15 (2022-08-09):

ESD protection

bstiq, 2022-08-09:
Quoting KarlK90:

ESD protection for USB-C port and split-comms port on data lines only or including cc lines (like shown)
protects against static discharge (charged cloths!) and subsequent destruction of any IC
recommendation StMicroelectronics (or knock-off manufacturer) USBLC6-2 in either SOT23-6L C7519 or the smaller SOT-666 C15999 package or the USBLC6-4 as shown

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

bstiq, 2022-09-14:
Scheduled for 2.0

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

Closed 2022-09-26.

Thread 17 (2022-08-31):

features/1.2

bstiq, 2022-08-31:
TODO

Fix ribbon cable twisting
- [ ] switch the order of the FPC cables
- [ ] change position of white dot

bstiq, 2022-09-16:
received the new prototypes and it seems to work well, will have to do a full build

bstiq, 2022-10-21:
Will do a 2.0 instead.

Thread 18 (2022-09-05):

Choc spaced version

yohcop, 2022-09-05:
Hi!

This is awesome!
Since it's meant to be a portable keyboard with input device, i was wondering if a choc-spaced version could be considered.

I realize with the case and all, it's not as trivial as just changing the spacing of the matrix :)

Best,

bstiq, 2022-09-06:
Hello,

I have no plans for a choc version at the moment.
It should be pretty easy to do though, just change the positioning of the switches and re-wire the matrix.
You will also have to change the edge cuts though, and the case will not be compatible anymore.

Regards,

Closed 2022-09-06.

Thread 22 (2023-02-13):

Resistor part number for left side

bstiq, 2023-02-13:
The 2 resistors for the left side on the trackpad connection do not have the right format (too big).
TODO: fix the part number in the BOM.

Closed 2023-02-27.

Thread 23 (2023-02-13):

Fix rotary encoder holes

bstiq, 2023-02-13:
At this moment the holes for the rotary encoder pins (plated) overlap with the holes for the switches (non plated).

TODO fix it.

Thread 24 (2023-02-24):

decoupling capacitor too close to sk6812 mini-e led on left half

bstiq, 2023-02-24:

Closed 2023-02-27.

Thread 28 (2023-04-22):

reset button shorts with leds

bstiq, 2023-04-22:

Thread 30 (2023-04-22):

fix silkscreen

bstiq, 2023-04-22:
- [ ] diodes
- [ ] etc

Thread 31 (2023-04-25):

get rid of diode cluster

bstiq, 2023-04-25:
replace with small diodes like on the assembled flex plates

bstiq, 2024-01-16:
moved to v3 todolist.

Closed 2024-01-16.

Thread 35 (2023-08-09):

MAX 1.0 notes

bstiq, 2023-08-09:
- [x] clean up silkscreen out of board
- [x] move D15, D5020 closer to edge
- [x] move matrix diodes out of silkscreen, closer to main components // easy to damage !!!. Also switch to bigger ones just in case
- [x] move top led further away from mouse bites
- [x] move bottom led a little bit down
- [x] move per-key rgb capacitor away from LED
- [x] fix gnd pattern....
- [x] update BOM - DIODES only, C22626
- [x] update POS - all

Closed 2023-09-13.

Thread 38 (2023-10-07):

V3 notes

bstiq, 2023-10-07:
- [x] fix lcd header
- [x] new silkscreen like max
- [x] revamp silkscreen letters like on the max
- [ ] ~~see through hole ?~~
- [x] gnd zones like on the max
- [x] update version number
- [x] reupdate silkscreen align BK logo properly
- [ ] ~~change to only sod123 diodes?~~
- [x] update per key led dots to follow jlc recommendations
- [x] North facing leds
- [x] Hotswap
- [x] Per Key rgb footprint like on Scylla (bigger edge cut) + GND/PINo1 marking
- [x] fix ec15 circle pin1
- [x] add update button to BOM and POS
- [x] check power traces are in .3
- [x] move update button under
- [x] remove encoder socket from BOM

others:
- [x] kailh sockets not working at jlc?
- [x] get rid of tiny rst button
- [x] make BOOT jumper a button

footprint:

- [ ] add 2 outer screws like on max
- [ ] find a spot for hole like on max?
- [ ] add silkscreen outer edge "dilemma"/original design etc, IF space and does not collide with silkscreen

silkscreen work:

- [x] flip update button footprint
- [x] change v1/CH to V3

bstiq, 2024-08-04:
Now waiting for the prototypes, will create a separate issue if needed.

Closed 2024-08-04.

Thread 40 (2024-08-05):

V3.1 issues

bstiq, 2024-08-05:
too close:
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

silkscreen issue (stars):
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

Align bottom silkscreen better

bstiq, 2024-08-05:
fixed as of 3.1+

Closed 2024-08-05.

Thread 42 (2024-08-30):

MAX V3 notes

bstiq, 2024-08-30:
- [ ] 180 degree rotation Choc switches
- [ ] update version number
- [ ] update sk6805 and sk6812 footprints to match dilemma v3
- [ ] add update button to BOM and POS
- [ ] check power traces are in .3
- [ ] move update button under
- [ ] change small reset button to tht holes
- [ ] change boot jumper into button
- [ ] remove encoder socket from BOM

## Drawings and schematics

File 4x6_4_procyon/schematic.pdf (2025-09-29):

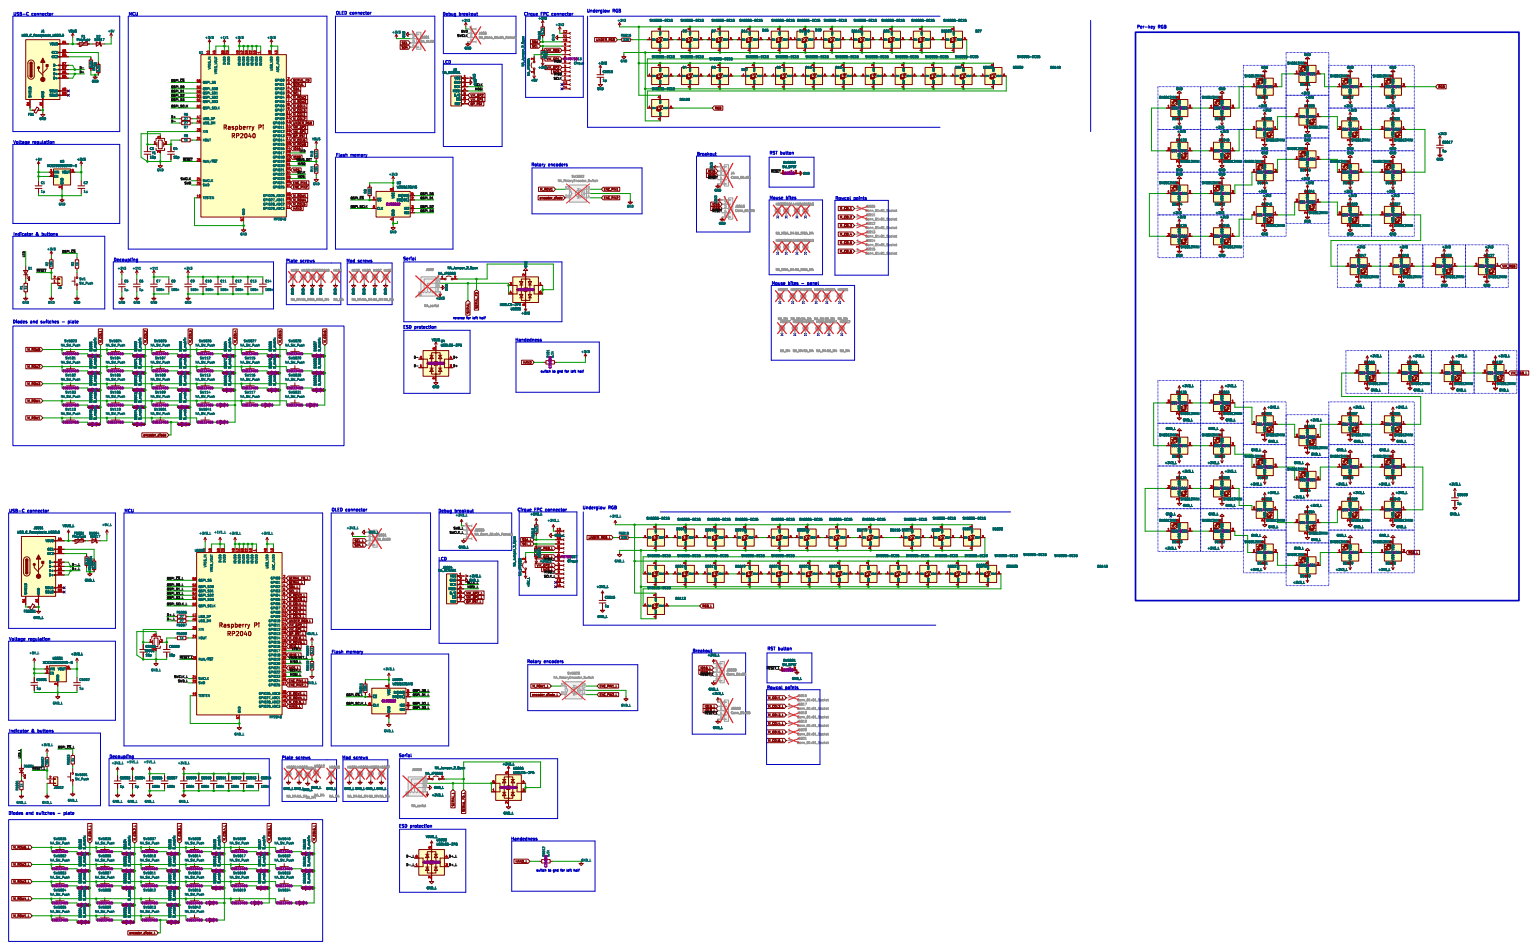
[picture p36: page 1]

Diodes and switches - plate

switch to gnd for left half

switch to gnd for left half Mod screws

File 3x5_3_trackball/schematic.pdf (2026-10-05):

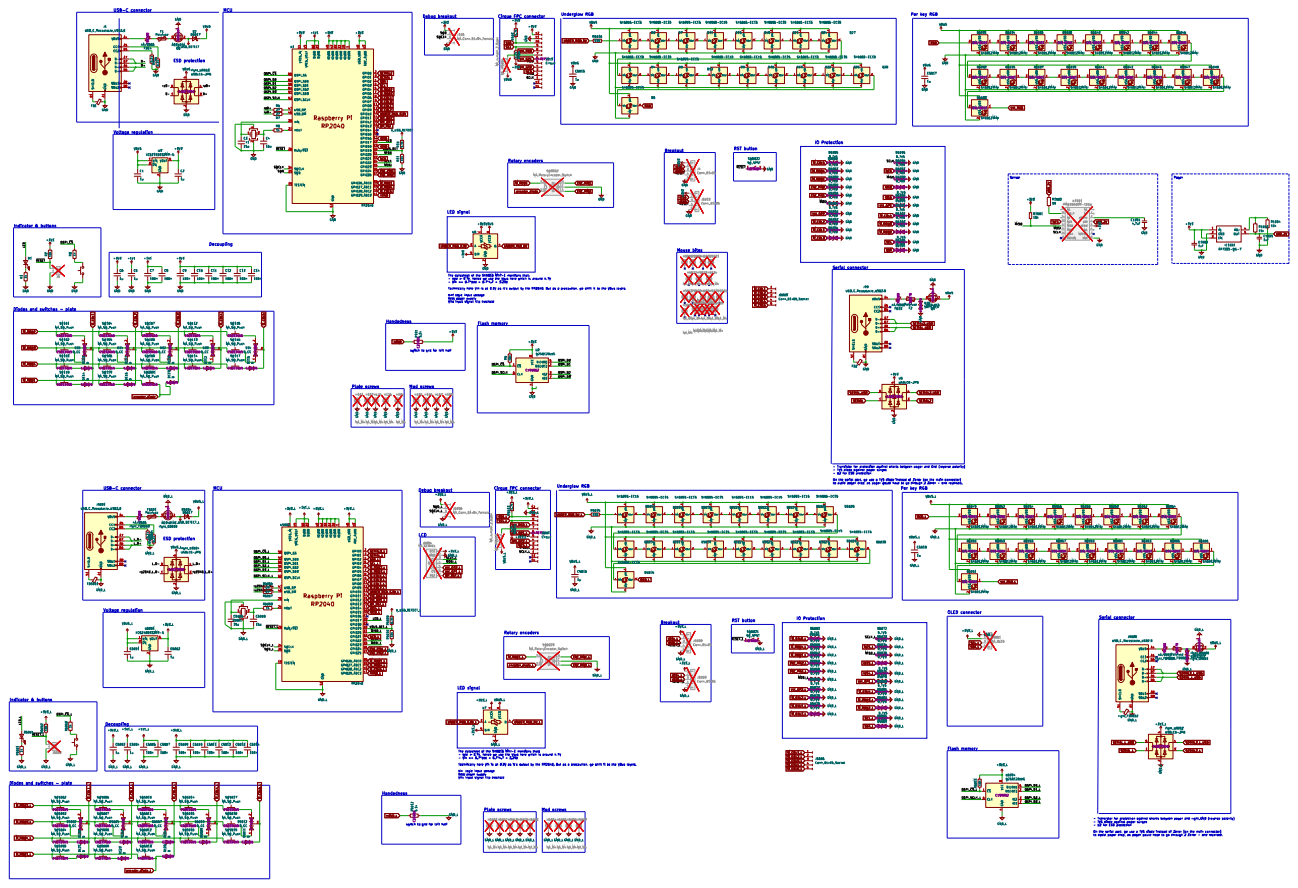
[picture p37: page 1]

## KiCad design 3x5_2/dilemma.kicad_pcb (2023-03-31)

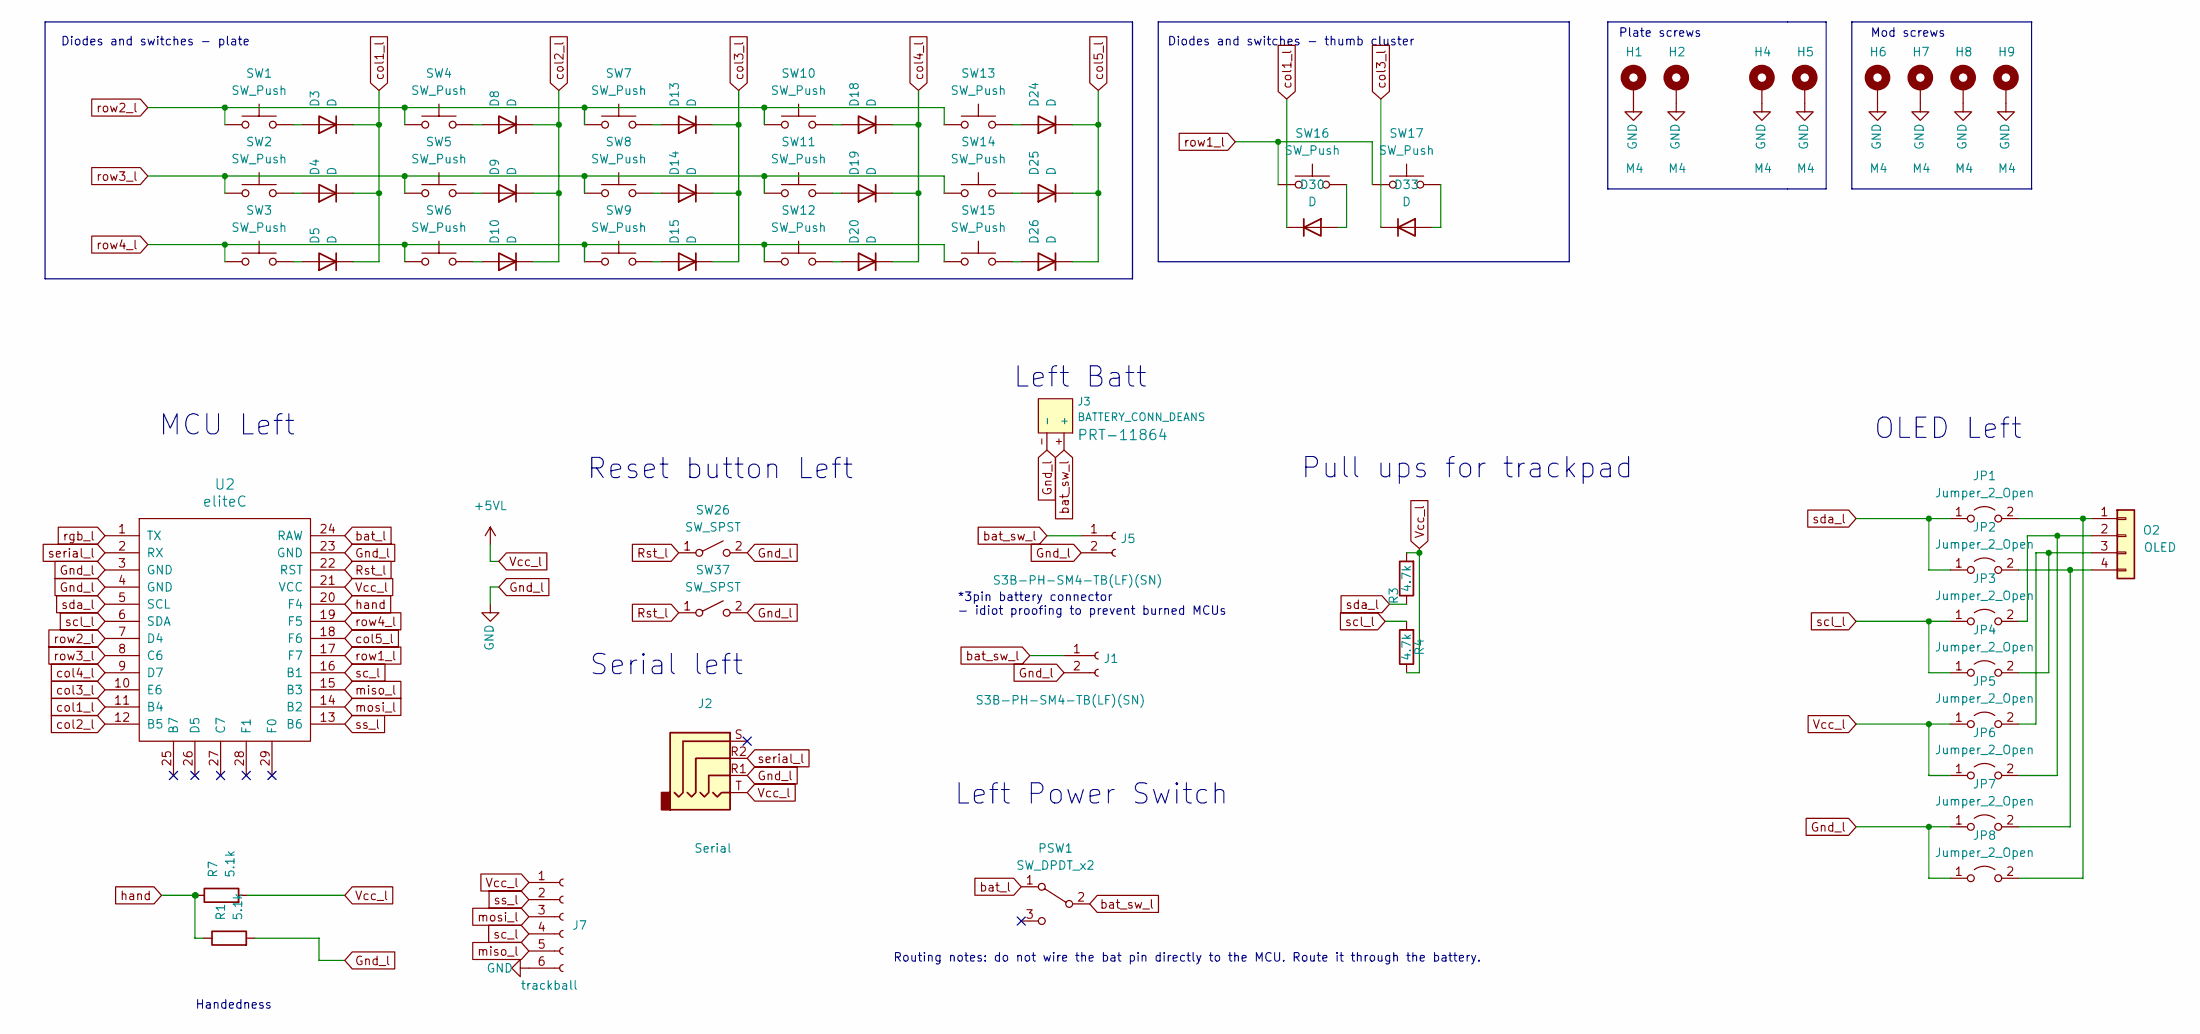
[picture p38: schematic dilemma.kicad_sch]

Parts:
D3, D4, D5, D8, D9, D10, D13, D14, D15, D18, D19, D20, D24, D25, D26, D30, D33: D; D_1206_handsolder_reversible
H1, H2, H4, H5, H6, H7, H8, H9: M4; MountingHole_3mm_Pad_thin
J1, J5: S3B-PH-SM4-TB(LF)(SN); JST_SH_BM02B-SRSS-TB_1x02-1MP_P1.00mm_Vertical; LCSC C265101
J2: Serial; Jack_3.5mm_PJ320E_Horizontal_reversible
J3: BATTERY_CONN_DEANS; battery_connector_THT
J7: trackball; 6_PinHeader
JP1, JP2, JP3, JP4, JP5, JP6, JP7, JP8: Jumper_2_Open; SolderJumper-2_P1.3mm_Open_RoundedPad1.0x1.5mm
O2: OLED; PinHeader_1x04_P2.54mm_Vertical
PSW1: SW_DPDT_x2; Switch_MSK-12C01-07; LCSC C431540
R1, R7: 5.1k; R_1206_handsolder; JLCPCB BOM 1
R3, R4: 4.7k; R_1206_handsolder_reversible; LCSC C269746
SW1, SW2, SW3, SW4, SW5, SW6, SW7, SW8, SW9, SW10, SW11, SW12, SW13, SW14, SW15, SW16, SW17: SW_Push; SW_MX_choc
SW26, SW37: SW_SPST; SW_Push_1P1T_NO_6x6mm_H9.5mm
U2: eliteC; pro-micro

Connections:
Gnd_l: H1.1, H2.1, H4.1, H5.1, H6.1, H7.1, H8.1, H9.1, J1.2, J2.R1, J3.-, J5.2, J7.6, JP7.1 (A), JP8.1 (A), R1.2, SW26.2 (B), SW37.2 (B), U2.3 (GND), U2.4 (GND), U2.23 (GND)
unnamed: D3.2 (A), SW1.2
unnamed: D4.2 (A), SW2.2
unnamed: D5.2 (A), SW3.2
unnamed: D8.2 (A), SW4.2
unnamed: D9.2 (A), SW5.2
unnamed: D10.2 (A), SW6.2
unnamed: D13.2 (A), SW7.2
unnamed: D14.2 (A), SW8.2
unnamed: D15.2 (A), SW9.2
unnamed: D18.2 (A), SW10.2
unnamed: D19.2 (A), SW11.2
unnamed: D20.2 (A), SW12.2
unnamed: D24.2 (A), SW13.2
unnamed: D25.2 (A), SW14.2
unnamed: D26.2 (A), SW15.2
unnamed: D30.2 (A), SW16.2
unnamed: D33.2 (A), SW17.2
unnamed: JP1.2 (B), JP8.2 (B), O2.1
unnamed: JP2.2 (B), JP7.2 (B), O2.4
unnamed: JP3.2 (B), JP6.2 (B), O2.2
unnamed: JP4.2 (B), JP5.2 (B), O2.3
Rst_l: SW26.1 (A), SW37.1 (A), U2.22 (RST)
Vcc_l: J2.T, J7.1, JP5.1 (A), JP6.1 (A), R3.2, R4.1, R7.2, U2.21 (VCC)
bat_l: PSW1.1 (A), U2.24 (RAW)
bat_sw_l: J1.1, J3.+, J5.1, PSW1.2 (B)
col1_l: D3.1 (K), D4.1 (K), D5.1 (K), D30.1 (K), U2.11 (B4)
col2_l: D8.1 (K), D9.1 (K), D10.1 (K), U2.12 (B5)
col3_l: D13.1 (K), D14.1 (K), D15.1 (K), D33.1 (K), U2.10 (E6)
col4_l: D18.1 (K), D19.1 (K), D20.1 (K), U2.9 (D7)
col5_l: D24.1 (K), D25.1 (K), D26.1 (K), U2.18 (F6)
hand: R1.1, R7.1, U2.20 (F4)
miso_l: J7.5, U2.15 (B3)
mosi_l: J7.3, U2.14 (B2)
rgb_l: U2.1 (TX)
row1_l: SW16.1, SW17.1, U2.17 (F7)
row2_l: SW1.1, SW4.1, SW7.1, SW10.1, SW13.1, U2.7 (D4)
row3_l: SW2.1, SW5.1, SW8.1, SW11.1, SW14.1, U2.8 (C6)
row4_l: SW3.1, SW6.1, SW9.1, SW12.1, SW15.1, U2.19 (F5)
sc_l: J7.4, U2.16 (B1)
scl_l: JP3.1 (A), JP4.1 (A), R4.2, U2.6 (SDA)
sda_l: JP1.1 (A), JP2.1 (A), R3.1, U2.5 (SCL)
serial_l: J2.R2, U2.2 (RX)
ss_l: J7.2, U2.13 (B6)

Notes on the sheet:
MCU Left
Left Batt
Handedness
Plate screws
Routing notes: do not wire the bat pin directly to the MCU. Route it through the battery.
Serial left
Diodes and switches - plate
Reset button Left
Pull ups for trackpad
Mod screws
Left Power Switch
OLED Left
Diodes and switches - thumb cluster
*3pin battery connector - idiot proofing to prevent burned MCUs

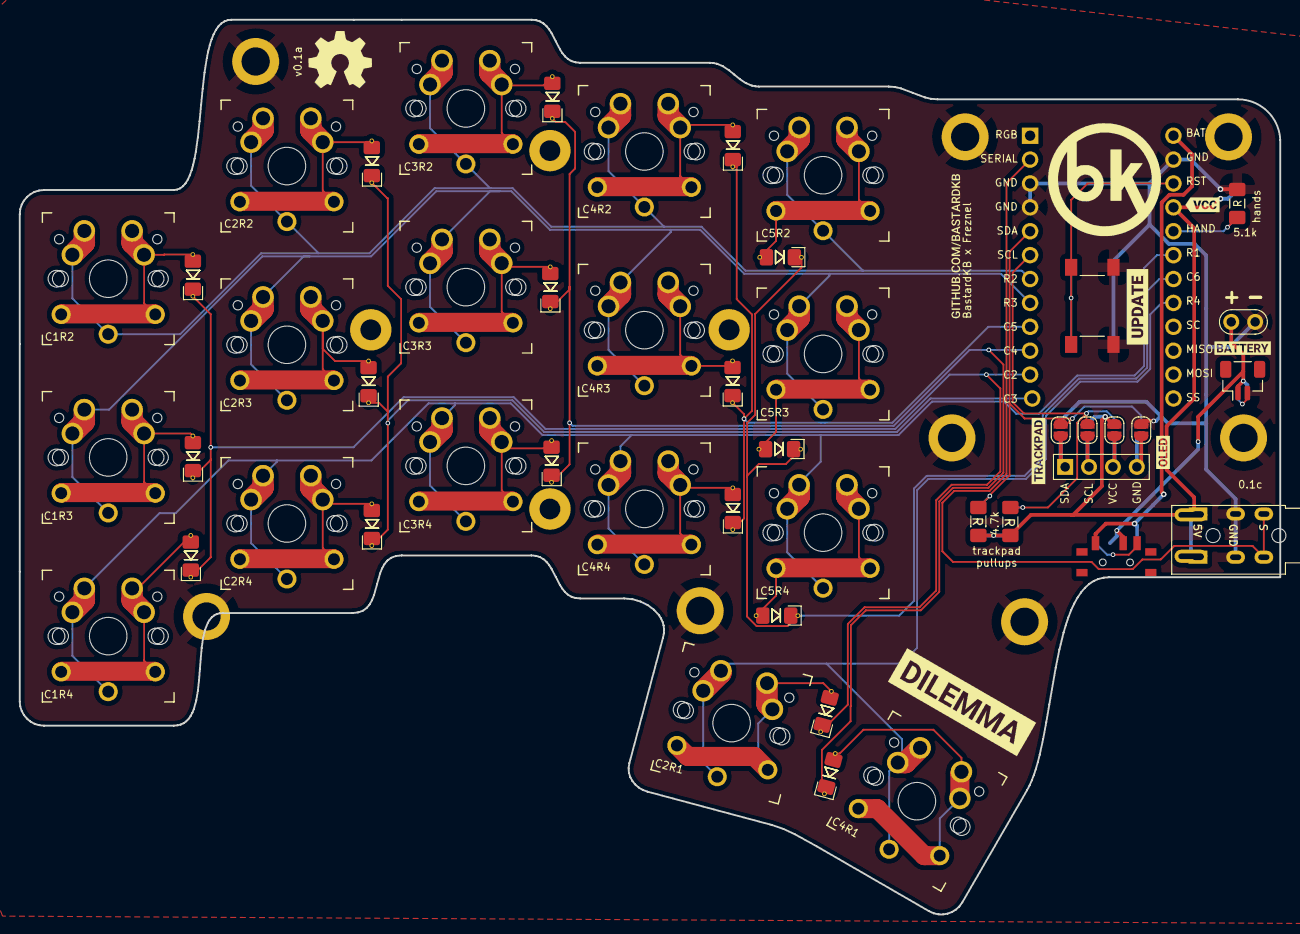
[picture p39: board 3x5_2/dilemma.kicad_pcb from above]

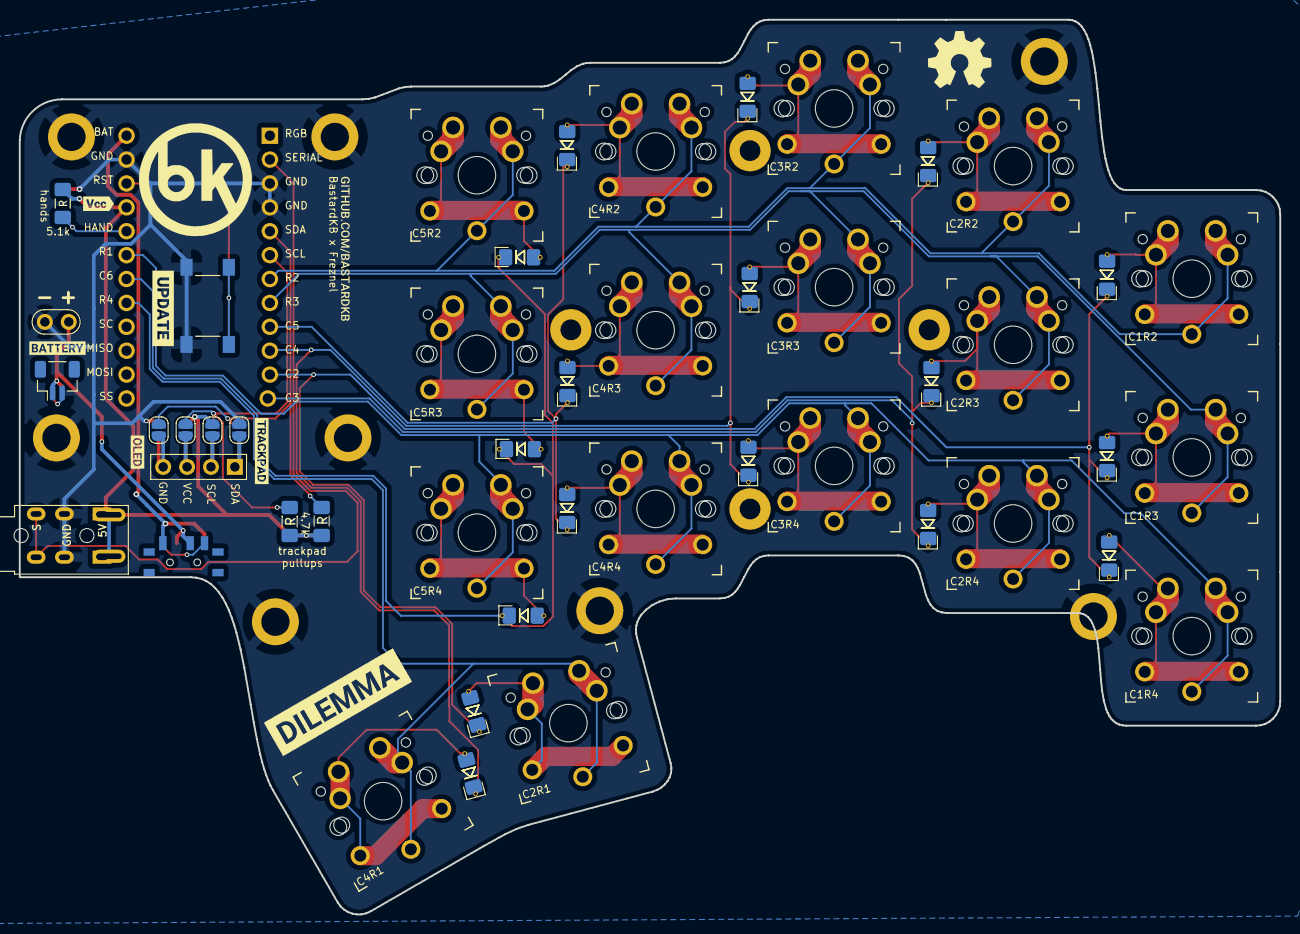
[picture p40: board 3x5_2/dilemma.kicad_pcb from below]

Board: 2 copper layers, 134.0 x 95.1 mm, 77 parts (15 on the bottom side), 39 nets.

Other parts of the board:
kibuzzard-61F01A92, kibuzzard-61F01A92#2: G***; kibuzzard-61F01A92
kibuzzard-61F01C84, kibuzzard-61F01C84#2: G***; kibuzzard-61F01C84
kibuzzard-628D3AA1: G***; kibuzzard-628D3AA1
kibuzzard-628D396A: G***; kibuzzard-628D396A
kibuzzard-628DFB5F, kibuzzard-628DFB5F#2: G***; kibuzzard-628DFB5F
kibuzzard-628DFB48, kibuzzard-628DFB48#2: G***; kibuzzard-628DFB48
kibuzzard-628DFB95, kibuzzard-628DFB95#2: G***; kibuzzard-628DFB95
kibuzzard-628E0199, kibuzzard-628E0199#2: G***; kibuzzard-628E0199

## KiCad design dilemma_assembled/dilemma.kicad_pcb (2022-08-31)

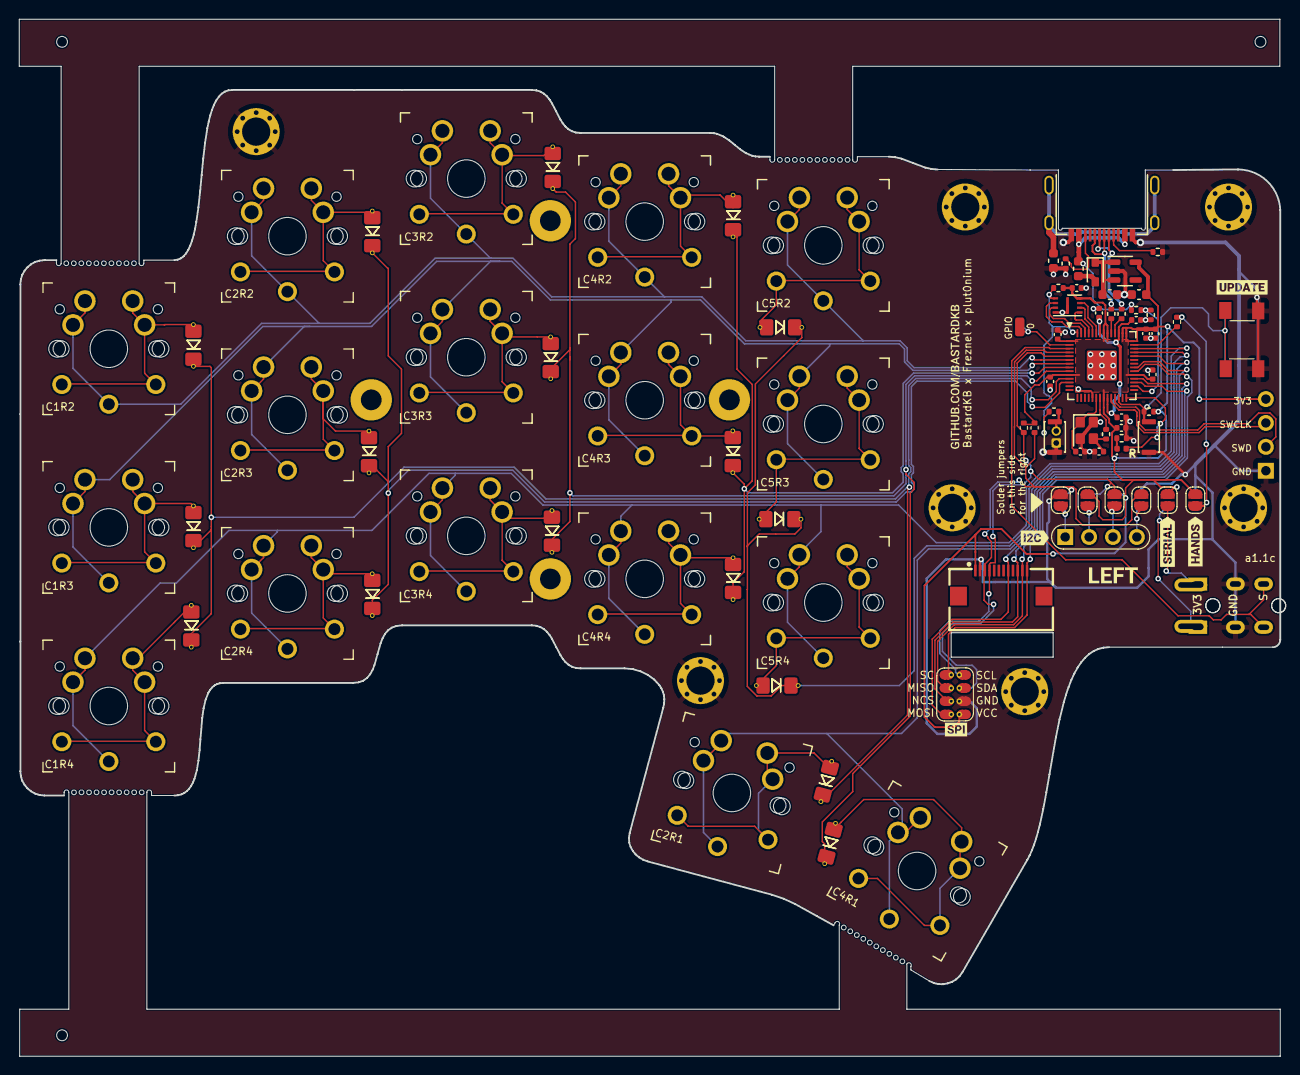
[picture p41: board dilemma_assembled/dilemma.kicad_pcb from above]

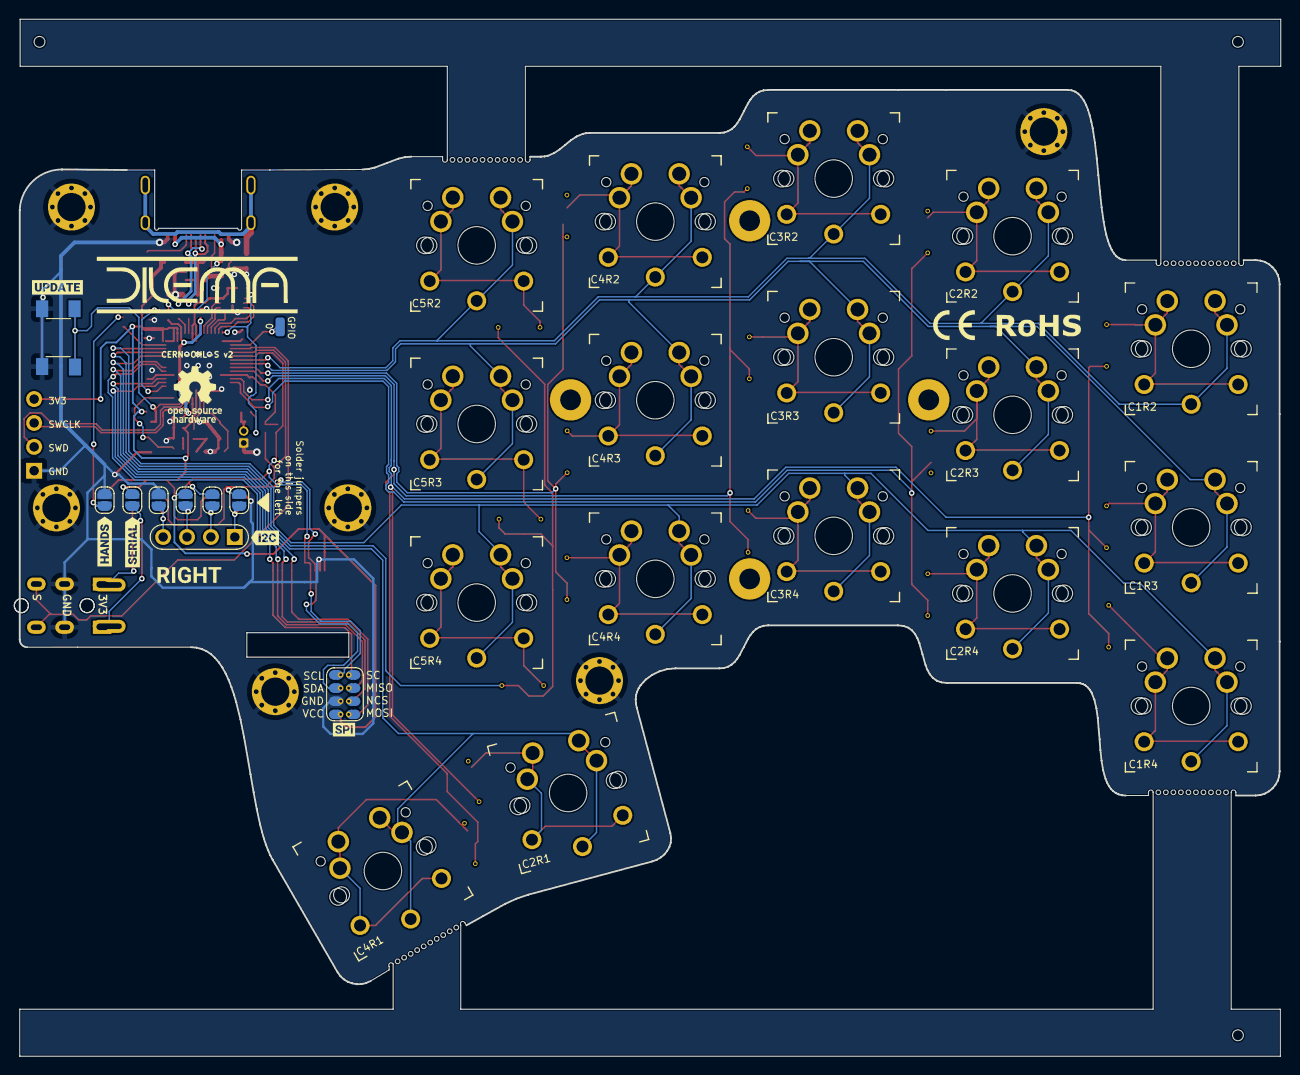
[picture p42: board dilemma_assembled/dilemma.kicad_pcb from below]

Board: 2 copper layers, 134.1 x 110.3 mm, 119 parts (15 on the bottom side), 71 nets.

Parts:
C1, C2: 1µ; C_0603_1608Metric
C3, C4: 15p; C_0402_1005Metric
C5, C6: 1µ; C_0402_1005Metric
C7, C8, C9, C10, C11, C12, C13, C14: 100n; C_0402_1005Metric
D1: LED; LED_0402_1005Metric
D2: B5817; D_SOD-323
D101, D102, D103, D104, D105, D106, D107, D108, D109, D110, D111, D112, D113, D114, D115, D116, D117: D; D_1206_handsolder_reversible
F1: Polyfuse; Fuse_0603_1608Metric
FB1: FerriteBead_Small; L_0603_1608Metric
H101, H102, H104, H105, H106, H107, H108: M4; MountingHole_3mm_Pad_Via
H103, H109, H110: t; JLC_SMT_Assembly_Hole
J1: USB_C_Receptacle_USB2.0; USB_C_Receptacle_HRO_TYPE-C-31-M-13B
J5: Conn_01x02; PinHeader_1x02_P1.27mm_Vertical
J102, J103: Serial; Jack_3.5mm_PJ320E_Horizontal_custom
J105: Conn_01x04_Female; PinHeader_1x04_P2.54mm_Vertical_debug
J107: Conn_01x08_Female; 1x08 smd reversible
J108, J109: Conn_01x01_Female; SolderWirePad_1x01_SMD_1x2mm
J113: Cirque; FPC-SMD_FPC05012-09200-.5mm
JP101, JP102, JP103, JP104, JP105, JP106, JP107, JP108, JP109, JP110, JP111, JP112: Jumper_2_Open; SolderJumper-2_P1.3mm_Open_RoundedPad1.0x1.5mm
O101: OLED; PinHeader_1x04_P2.54mm_Vertical
R1, R3, R8: 1k; R_0402_1005Metric
R2, R9, R11: 10k; R_0402_1005Metric
R4, R5, R10: 5.1k; R_0402_1005Metric
R6, R7: 27; R_0402_1005Metric
R101: 5.1k; R_0402_1005Metric_nolabel
R103, R104: 4.7k; R_0402_1005Metric_nolabel
SW1, SW2: SW_Push; SW_SPST_CK_KXT3
SW101, SW102, SW103, SW104, SW105, SW106, SW107, SW108, SW109, SW112, SW113, SW114, SW115, SW116, SW117, SW118: SW_Push; SW_MX_choc
SW110, SW111: SW_SPST; SW_Push_1P1T_NO_6x6mm_H9.5mm
SW119: locked; SW_MX_choc
U1: RP2040; QFN-56-1EP_7x7mm_P0.4mm_EP3.2x3.2mm
U2: GD25Q80CEIGR; USON-8-1EP_3x2mm_P0.5mm_EP0.25x1.65mm
U3: XC6210B332MR-G; SOT-23-5
Y1: Crystal_GND24; Crystal_SMD_2520-4Pin_2.5x2.0mm
kibuzzard-61F01A92: G***; kibuzzard-61F01A92
kibuzzard-62C1A775, kibuzzard-62C1A775#2: G***; kibuzzard-62C1A775
kibuzzard-62C19A64, kibuzzard-62C19A64#2: G***; kibuzzard-62C19A64
kibuzzard-62C19AB4: G***; kibuzzard-62C19AB4
kibuzzard-62C19AC2: G***; kibuzzard-62C19AC2
kibuzzard-62C19AE7, kibuzzard-62C19AE7#2: G***; kibuzzard-62C19AE7
kibuzzard-62C55DF6, kibuzzard-62C55DF6#2: G***; kibuzzard-62C55DF6
kibuzzard-62C547B3: G***; kibuzzard-62C547B3
kibuzzard-62C5480E: G***; kibuzzard-62C5480E

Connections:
+1V1: C6.1, C7.1, C8.1, U1.23 (DVDD), U1.45 (VREG_VOUT), U1.50 (DVDD)
+3V3: C2.1, C5.1, C9.1, C10.1, C11.1, C12.1, C13.1, C14.1, J105.1, J107.1, J113.1, JP101.2 (B), JP102.2 (B), JP107.1 (A), JP108.1 (A), JP112.2 (B), R2.2, R9.2, R103.2, R104.1, U1.1 (IOVDD), U1.10 (IOVDD), U1.22 (IOVDD), U1.33 (IOVDD), U1.42 (IOVDD), U1.43 (ADC_AVDD), U1.44 (VREG_IN), U1.48 (USB_VDD), U1.49 (IOVDD), U2.8 (VCC), U3.5 (VOUT)
/D+: J1.A6 (D+), J1.B6 (D+), R6.1
/D-: J1.A7 (D-), J1.B7 (D-), R7.1
/LED: D1.2 (A), U1.28 (GPIO17)
/QSPI_D0: U1.53 (QSPI_SD0), U2.5 (DI(IO0))
/QSPI_D1: U1.55 (QSPI_SD1), U2.2 (DO(IO1))
/QSPI_D2: U1.54 (QSPI_SD2), U2.3 (IO2)
/QSPI_D3: U1.51 (QSPI_SD3), U2.7 (IO3)
/QSPI_SCLK: U1.52 (QSPI_SCLK), U2.6 (CLK)
/QSPI_~CS: R3.2, R9.1, U1.56 (QSPI_SS), U2.1 (~CS)
/SWCLK: J105.2, U1.24 (SWCLK)
/SWD: J105.3, U1.25 (SWD)
/VBUS_DET: R10.1, R11.2, U1.30 (GPIO19)
Gnd_l: C1.2, C2.2, C3.2, C4.2, C5.2, C6.2, C7.2, C8.2, C9.2, C10.2, C11.2, C12.2, C13.2, C14.2, FB1.1, H101.1, H102.1, H104.1, H105.1, H106.1, H107.1, H108.1, J1.A1 (GND), J1.A12 (GND), J1.B1 (GND), J1.B12 (GND), J5.1, J102.R1, J103.R1, J105.4, J107.2, J113.2, JP109.1 (A), JP110.1 (A), JP111.2 (B), R1.1, R4.1, R5.1, R11.1, SW1.1, SW2.1, SW110.2 (B), SW111.2 (B), U1.19 (TESTEN), U1.57 (GND), U2.4 (GND), U2.9 (EP), U3.2 (GND), Y1.2, Y1.4
NCS: J107.6, J113.10, U1.32 (GPIO21)
unnamed: C3.1, U1.20 (XIN), Y1.1
unnamed: C4.1, R8.1, Y1.3
unnamed: D1.1 (K), R1.2
unnamed: D2.2 (A), F1.2
unnamed: D101.2 (A), SW101.2
unnamed: D102.2 (A), SW102.2
unnamed: D103.2 (A), SW103.2
unnamed: D104.2 (A), SW104.2
unnamed: D105.2 (A), SW105.2
unnamed: D106.2 (A), SW106.2
unnamed: D107.2 (A), SW107.2
unnamed: D108.2 (A), SW108.2
unnamed: D109.2 (A), SW109.2
unnamed: D110.2 (A), SW112.2
unnamed: D111.2 (A), SW113.2
unnamed: D112.2 (A), SW114.2
unnamed: D113.2 (A), SW115.2
unnamed: D114.2 (A), SW116.2
unnamed: D115.2 (A), SW117.2
unnamed: D116.2 (A), SW118.2
unnamed: D117.2 (A), SW119.2
unnamed: FB1.2, J1.S1 (SHIELD)
unnamed: J1.A5 (CC1), R4.2
unnamed: J1.B5 (CC2), R5.2
unnamed: J5.2, R3.1, SW2.2
unnamed: J102.T, JP101.1 (A)
unnamed: J103.T, JP102.1 (A)
unnamed: JP103.2 (B), JP110.2 (B), O101.1
unnamed: JP104.2 (B), JP109.2 (B), O101.4
unnamed: JP105.2 (B), JP108.2 (B), O101.2
unnamed: JP106.2 (B), JP107.2 (B), O101.3
unnamed: JP111.1 (A), JP112.1 (A), R101.2
unnamed: R6.2, U1.47 (USB_DP)
unnamed: R7.2, U1.46 (USB_DM)
unnamed: R8.2, U1.21 (XOUT)
Rst_l: R2.1, SW1.2, SW110.1 (A), SW111.1 (A), U1.26 (RUN/~RST)
VBUS: F1.1, J1.A4 (VBUS), J1.A9 (VBUS), J1.B4 (VBUS), J1.B9 (VBUS), R10.2
bat_l: C1.1, D2.1 (K), U3.1 (VIN), U3.3 (EN)
col1_l: D101.1 (K), D102.1 (K), D103.1 (K), D116.1 (K), U1.11 (GPIO8)
col2_l: D104.1 (K), D105.1 (K), D106.1 (K), U1.12 (GPIO9)
col3_l: D107.1 (K), D108.1 (K), D109.1 (K), D117.1 (K), U1.9 (GPIO7)
col4_l: D110.1 (K), D111.1 (K), D112.1 (K), U1.8 (GPIO6)
col5_l: D113.1 (K), D114.1 (K), D115.1 (K), U1.39 (GPIO27_ADC1)
hand: R101.1, U1.41 (GPIO29_ADC3)
miso_l: J107.7, J113.11, U1.31 (GPIO20)
mosi_l: J107.5, J113.8, U1.35 (GPIO23)
rgb_l: J108.1, J109.1, U1.2 (GPIO0)
row1_l: SW118.1, SW119.1, U1.38 (GPIO26_ADC0)
row2_l: SW101.1, SW104.1, SW107.1, SW112.1, SW115.1, U1.6 (GPIO4)
row3_l: SW102.1, SW105.1, SW108.1, SW113.1, SW116.1, U1.7 (GPIO5)
row4_l: SW103.1, SW106.1, SW109.1, SW114.1, SW117.1, U1.40 (GPIO28_ADC2)
sc_l: J107.8, J113.12, U1.34 (GPIO22)
scl_l: J107.4, J113.4, JP105.1 (A), JP106.1 (A), R104.2, U1.5 (GPIO3)
sda_l: J107.3, J113.3, JP103.1 (A), JP104.1 (A), R103.1, U1.4 (GPIO2)
serial_l: J102.R2, J103.R2, U1.3 (GPIO1)

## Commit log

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2022-05-14 go back to 3x5
    [unnamed.kicad_sch]
2022-05-14 rgb left and right
    [unnamed.kicad_sch]
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2022-05-14 Added 3 pin battery connector
    3pin battery connector - idiot proofing to prevent burned MCUs
    [unnamed.kicad_sch]
2022-05-14 Added Cirque FFC connector
    Added FFC while prototyping other connection solutions. Need to check how to power Cirque since it's rated up to 3.6v only.
    [unnamed.kicad_sch]
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2022-05-14 Added OLED
    SSD1306 OLED. Might include jumpers to bigger SH1107 (hi drashna!) OLED. Also planning to ad SPI screen pin headers.
    [unnamed.kicad_sch]
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2022-05-20 CirqueDB initial commit
    CirqueDB initial commit
    [BK-CirqueDB.kicad_pcb, BK-CirqueDB.kicad_sch, BK-CirqueDB.step]
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2022-05-24 routing, audio jack, rst button
    [unnamed.kicad_pcb, unnamed.kicad_sch]
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2022-05-25 bigger thermal relief pads
    [dilemma.kicad_pcb]
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2022-05-25 move battery connector and screw hole
    [dilemma.kicad_pcb]
2022-05-25 make trackpad pinout compatible with oled
    [BK-CirqueDB.kicad_pcb, BK-CirqueDB.kicad_sch]
2022-05-25 move cirque daughterboard to its own repo
    [BK-CirqueDB.kicad_pcb, BK-CirqueDB.kicad_sch, BK-CirqueDB.step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]
2022-05-26 Added battery THT and the most common power switch used for wireless builds
    Added battery THT and the most common power switch used for wireless builds
    [dilemma.kicad_pcb, dilemma.kicad_sch]
2022-05-26 clean up battery tht connector
    [dilemma.kicad_pcb, dilemma.kicad_sch]
2022-05-26 connect power switch pads
    [dilemma.kicad_pcb]
2022-05-26 Footprint cleanup
    Added power switch footprint to local lib
    [dilemma.kicad_pcb, dilemma.step]
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2022-07-06 add breakout pad for gpio2
    [0xB2.kicad_pcb, 0xB2.kicad_sch]
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2022-07-08 remove assembled battery connector
    [0xB2.kicad_pcb]
2022-07-11 fix resistor value
    [0xB2.kicad_pcb]
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2022-07-21 add rohs ce marking
    [dilemma.kicad_pcb]
2022-07-21 fix gpio number
    [dilemma.kicad_pcb]
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2022-07-21 add back diy version
    [dilemma.kicad_pcb, dilemma.kicad_sch, dilemma.step]
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2022-07-24 make 5v breakout tht
    [dilemma.kicad_sch]
2022-07-24 fix power switch
    [dilemma.kicad_pcb, dilemma.kicad_sch]
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2022-08-02 remove half plate screw
    [dilemma.kicad_pcb, dilemma.kicad_sch]
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2022-08-08 flip i2c
    [dilemma.kicad_pcb]
2022-08-08 bigger usb c cutouts
    [tenting_puck_v3_24.stl, tenting_puck_v3_26.stl, thin_v1_25.stl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]
2022-08-08 rounded angle around audio jack
    [dilemma.kicad_pcb]
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2022-08-08 fix bom
2022-08-08 add tooling holes, fancy M3 holes with vias
    [dilemma.kicad_sch]
2022-08-08 add back mouse bites
    [dilemma.kicad_sch]
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2022-08-10 change position of mouse bites
    [dilemma.kicad_pcb]
2022-08-31 switch up fpc connections
    [dilemma.kicad_pcb, dilemma.kicad_sch]
2022-09-05 add back tenting puck
    [dilemma.kicad_pcb, dilemma.kicad_sch]
2022-09-12 add thumb key and encoder
    [dilemma.kicad_pcb, dilemma.kicad_sch]
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2022-09-18 add sk6805 rgb 3d model
    [SK6805-EC15 v2.step, dilemma.kicad_pcb]
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2022-09-23 switch rgb to smd connectors
    [dilemma.kicad_pcb, dilemma.kicad_sch]
2022-09-26 flip debug headers
    [dilemma.kicad_pcb, dilemma.kicad_sch]
2022-09-26 routing, non assembled components
    [dilemma.kicad_sch]
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2022-10-03 add usb c cutout
    [dilemma.kicad_sch, plate.dxf]
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2022-10-04 fix per key RGB connection
    [dilemma.kicad_pcb, dilemma.kicad_sch]
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2022-10-13 add gnd markings on per key rgb leds
    [dilemma.kicad_pcb]
2022-11-03 add community mod files
    [Blank Cover.STEP, Blank Cover.stl, Cirque TM040040-2024-302 Holder Bottom.STEP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]
2022-11-22 connect rotary encoder pins
    [dilemma.kicad_sch]
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2022-11-23 bigger holes for per key rgb plate
    [dilemma.kicad_pcb]
2022-11-23 add left side (temporary)
    [0xB2-Edge_Cuts.dxf, SK6805-EC15 v2.step, dilemma.kicad_sch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]
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2022-12-13 fix diodes
2022-12-13 remove per key rgb folder
    [dilemma.kicad_pcb, dilemma.kicad_sch, plate.dxf]
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2023-01-08 add per key RGB
    [dilemma.kicad_sch]
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2023-01-10 switch vcc gnd on lcd
    [dilemma.kicad_sch]
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2023-02-27 fix rotary encoder holes
2023-03-08 fix bom, update to kicad 7
    [dilemma.kicad_sch]
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2023-03-15 fix led thermal reliefs
2023-04-25 add esd on serial
    [dilemma.kicad_sch]
2023-04-25 fix led orientation
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2023-06-01 fix encoder trace too close
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2023-07-20 place and fill in ec15 leds
    [dilemma.kicad_sch]
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2023-07-20 place per key rgb leds right
    [dilemma.kicad_sch]
2023-07-20 plate per key rgb right side
    [dilemma.kicad_sch]
2023-07-20 left per key rgb
    [dilemma.kicad_sch]
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2023-08-02 fix lcd pinout
    [dilemma.kicad_sch]
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2023-08-28 fix gnd pattern
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2023-09-14 update case to fit new led positions
    [top.3mf]
2023-10-02 add 4x6 acrylic dxf
    [acrylic.dxf]
2023-10-04 add MAX unibody 20 deg
    [center_20deg.stl, outer.stl]
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2023-10-08 fix lcd header
    [dilemma.kicad_sch]
2023-10-08 change flash header to SMD
    [dilemma.kicad_sch]
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2023-11-20 better top 3x5 case
    [top.stl]
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2024-07-22 flip update button side, add to BOM
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2024-07-26 flip rst and boot footprints
    [dilemma.kicad_sch]
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2024-08-05 fix silkscreen
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2024-08-30 add 3d files, revamp readme
    [hider_left_v6.stl, left_v6.stl, spacer_right_v82.stl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]
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2025-02-14 Revert "switch to V cuts"
    This reverts commit 9a77199dbe4cfd7d299bf905d5d65e3872fdc642.
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2025-02-20 add pics, clean up readme, add 3d files
    [bottom.stl, hider_left_v6.stl, left_v6.stl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]
2025-02-21 add back non hotswap 3x5_3
    [SK6805-EC15 v2.step, dilemma-Edge_Cuts.dxf, dilemma.kicad_sch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]
2025-03-04 14.20mm wide choc switches
    [top_left.stl, top_right.stl]
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2025-04-01 update dilemma v3 mechanical parts
    [bottom.stl, mid.stl, midplate.dxf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]
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2025-05-29 everything fits a bit better
    [bottom.stl, hider.stl, holder.stl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]
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2025-06-20 remove tenting puck, fix mousebites
    [dilemma.kicad_sch]
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2025-08-05 Add tents for dilemma max
    [tent-15.stl, tent-5.stl, tent-7.stl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]
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2025-08-08 procyon trackpad: switch to spacers instead of heated inserts
    [holder.stl, spacer.stl]
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2025-09-29 add 4x6_4 3d parts and schematics
    [bottom.stl, hider_3x5.stl, hider_4x6.stl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]
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2025-11-10 Dilemma V2 Mounts init
    [dilemma_clamp_mount-left.stl, dilemma_clamp_mount-right.stl, dilemma_table_tent-left.stl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]
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

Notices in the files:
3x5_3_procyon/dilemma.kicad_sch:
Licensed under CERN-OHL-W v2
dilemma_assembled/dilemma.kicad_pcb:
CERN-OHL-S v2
